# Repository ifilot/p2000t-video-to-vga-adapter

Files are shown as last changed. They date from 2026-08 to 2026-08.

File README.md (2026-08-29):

# P2000T video-to-VGA adapter

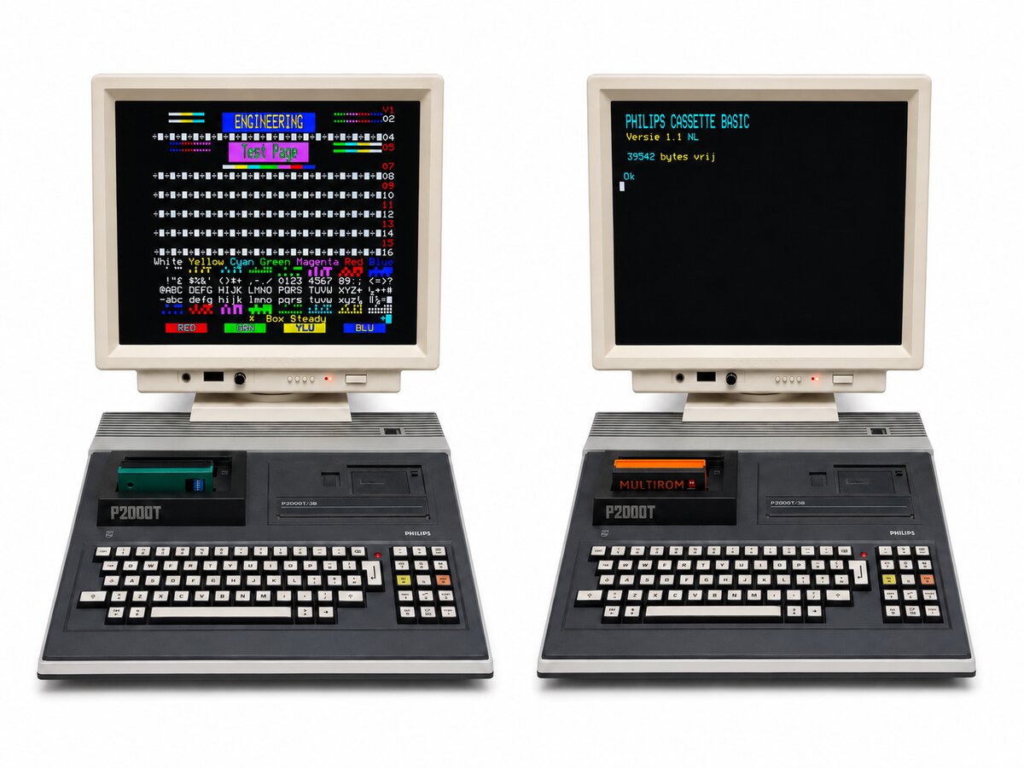
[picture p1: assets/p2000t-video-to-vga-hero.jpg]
Two Philips P2000T computers displaying the original RGBS output and converted VGA output






Hardware and firmware for converting the Philips P2000T RGBS output to
640×480 VGA using a Raspberry Pi Pico or Pico 2.

## Downloads

- [Latest Pico firmware](https://github.com/ifilot/p2000t-video-to-vga-adapter/releases/latest/download/p2000t-vid2vga-pico.uf2)
- [Latest Pico 2 firmware](https://github.com/ifilot/p2000t-video-to-vga-adapter/releases/latest/download/p2000t-vid2vga-pico2.uf2)
- [SAA5050 screen-test cartridge](https://github.com/ifilot/p2000t-video-to-vga-adapter/releases/latest/download/p2000t-screentest.bin)
- [Latest Windows capture viewer installer](https://github.com/ifilot/p2000t-video-to-vga-adapter/releases/latest/download/p2000t-vid2vga-capture-windows-setup.exe)
- [Latest portable Windows capture viewer](https://github.com/ifilot/p2000t-video-to-vga-adapter/releases/latest/download/p2000t-vid2vga-capture-windows.zip)

## Features

- 480×240 RGBs capture using PIO and DMA
- Triple-buffered, frame-boundary VGA updates
- Horizontally qualified CSYNC capture
- 640×480 at 60 Hz RGB444 VGA output
- Three selectable on-screen signal-loss designs
- On-board LED breathing while seeking and blinking during valid capture
- USB serial controls and capture statistics
- Pico 2 USB screen streaming at a target 25 FPS with a Qt 6 viewer
- Selectable raw, legacy guarded, sharp guarded, and Pico 2 three-sample
  126 MHz window reconstruction modes for studying transition instability
- CRC-protected persistence for every Pico 2 reconstruction mode

## Building

Install the Arm GNU toolchain, CMake, and Ninja. On Ubuntu or Debian, install
the required build packages with:

```sh
sudo apt update
sudo apt install cmake ninja-build gcc-arm-none-eabi \
  libnewlib-arm-none-eabi libstdc++-arm-none-eabi-newlib git python3
```

Configure and build the Pico firmware:

```sh
cmake -S . -B build -G Ninja -DCMAKE_BUILD_TYPE=Release -DPICO_BOARD=pico
cmake --build build --parallel
```

For Pico 2, use a separate build directory:

```sh
cmake -S . -B cmake-build-pico2 -G Ninja \
  -DCMAKE_BUILD_TYPE=Release -DPICO_BOARD=pico2
cmake --build cmake-build-pico2 --parallel
```

## USB controls

Connect to the Pico USB serial port and press `h` for help. Useful commands are
`s` for status, `[`/`]` for vertical position, `,`/`.` for sample phase, and
`;`/`'` for the odd-line phase correction. Use `{`/`}` to make the complete
captured line narrower or wider and `w` to reset that rate trim. `<`/`>` moves
the horizontal start, `d` toggles raw/guarded-second-tap reconstruction,
while `1`, `2`, or `3` selects the no-connection artwork.
Each phase tick is nominally 7.94 ns. Each rate step changes the PIO divider by
1/256 and moves the right edge by approximately 0.94 captured pixel while
leaving the sync-anchored left edge in place. Positive odd-line phase samples
odd physical source lines later; positive rate trim widens every line. Pico 2
v0.4.1 Pico 2 factory defaults use line-sliced `window-late` reconstruction
with phase `0`, odd-line correction `+1`, and rate trim `0`. The tuple was
validated against the complete animated teletext test page, including its
blue/white mosaic boundaries and both text polarities. The original Pico
retains raw reconstruction with phase-zero defaults.

Raw reconstruction exposes both 12 MHz samples in every nominal 6 MHz
SAA5050 source dot. Guarded-second-tap reconstruction uses the later sample
for both corresponding VGA pixels unless it matches neither the first tap nor
the following dot's first tap; that isolated intermediate color is replaced
by the current dot's first tap. Pico 2 window reconstruction captures a complete
high-resolution frame and decodes one source line per main-loop service slice;
this retained physical VGA output during live USB validation. It is enabled by
default on Pico 2 and can be omitted from a specialized build with
`-DP2000T_WINDOW_CAPTURE_ENABLED=OFF`. Existing explicitly saved settings remain
authoritative until the user invokes factory reset. Existing v0.3.x records are
migrated when next saved.

For a measured source period near 20092 us, start with rate trim `+2`. The
left-edge compensation allows the existing sample phase to remain unchanged;
compare both edges and also try `+1` because one divider step is necessarily
coarser than the calculated ideal correction.

On Pico 2, `c` starts the recommended continuous PackBits screen stream and
`r` starts an uncompressed stream. Press `q` or Escape to stop binary mode and
return to the console. The alignment and artwork commands remain available
silently while a binary stream is active, allowing the desktop viewer to
configure the adapter without interrupting capture. Stream protocol v4 adds a
64-bit Pico monotonic capture-completion timestamp to every record; the v0.4.1
viewer also accepts legacy v3 records. Factory reset restores and immediately
persists the known-good tuple, palette, and artwork in one USB operation.

> [!NOTE] 
> Screen streaming is intentionally excluded from the Pico/RP2040 build
> for now so its limited SRAM and established VGA timing remain unchanged.

## Pico 2 desktop capture viewer

The Windows viewer shows the P2000T screen live over USB and can save snapshots
as PNG files. It connects to the first detected Pico 2 automatically. When no
P2000T signal is present, it displays the same selected no-connection screen as
the VGA output.

Use **Adapter > Configure Pico 2** to adjust alignment, the independent
odd-line phase correction, and the horizontal sampling-rate trim; choose the
two-tap or 126 MHz window reconstruction; choose the no-connection artwork;
and tune all eight colors. Changes take effect
immediately, which makes calibration easy.
Settings can be restored, reset to their defaults, or saved to the Pico 2 for
the next power-on.

For capture-quality investigation, **Adapter > Record high-resolution
diagnostics** saves a full-frame 63 MHz CSYNC trace and repeated, sync-triggered
126 MHz raw RGBS bursts without reconstruction or palette conversion. See the
[diagnostic recording and analysis guide](docs/diagnostics.md).

For intermittent edge artifacts, **Adapter > Capture calibration sweep**
automatically tests an inclusive sample-phase x horizontal-rate range against
a static source screen. It waits a configurable number of frames after every
acknowledged change, saves multiple consecutive PNGs per setting, and records
the setting and source-frame sequence in a CSV manifest inside a timestamped
analysis directory. The odd-line correction remains fixed at its current
value, and the original live settings are restored after completion or
cancellation.

For unattended optimization, display the supplied SAA5050 screen-test
cartridge and choose **Adapter > Run engineering-screen autotune**. The viewer
forces sharp raw reconstruction, evaluates every phase/rate-trim pair, then
tunes the physical odd lines independently and validates the winner over a
longer run. It applies the result live without writing flash. Every retained
frame, modal candidate image, odd/even instability measurement, one-dot color
transient count, and selection decision is written to a timestamped analysis
directory. See the [engineering autotune guide](docs/engineering-autotune.md).

For AI-directed investigation, the invisible **Codex lab agent** owns the
Windows Pico connection without opening the viewer. Codex can query live state,
apply non-persistent sampling settings, explicitly persist a chosen tuple,
request settled multi-frame captures, receive modal/instability
metrics, inspect the PNGs, and adapt the next experiment without a person
operating a GUI. The Windows agent and WSL client exchange
atomic JSON files through `D:\tmp\p2000t-codex-lab`; see the
[Codex lab guide](docs/codex-lab.md).
The [windowed reconstruction design](docs/windowed-reconstruction.md) explains
the six-tap PIO path and its per-frame evidence counters.

Download either the installer or portable ZIP from [Downloads](#downloads).
The installer adds the viewer to the Start menu and includes an uninstaller.

## License

Firmware and viewer sources are
[GPL-3.0-or-later](LICENSES/GPL-3.0-or-later.txt). Hardware design files are
licensed under CERN-OHL-S-2.0; see [pcb/LICENSE.md](pcb/LICENSE.md).

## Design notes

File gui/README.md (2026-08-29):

# P2000T VID2VGA Capture

This deliberately small Qt 6 application discovers Raspberry Pi Pico USB CDC
ports, starts the Pico 2 binary RGB111 screen stream, verifies every frame with
CRC-32, and displays every 480×240 capture scanline twice as a square-pixel
480×480 image. It supports lossless PackBits or raw records and can save the
current frame as a PNG. When the P2000T signal is absent, the viewer reports
which of the three embedded no-connection screens the VGA output is showing
and reproduces that complete 640×480 screen from the same RGB444 artwork,
bitmap font, and overlay coordinates used by the firmware.

The application carries its retro-computing icon in the Qt resources and as a
multi-resolution Windows executable icon; no separate image files are needed
beside the packaged executable. Its menu actions use a matching late-1990s
Linux desktop-inspired icon set embedded in the same resource bundle.

When launched, the viewer attempts to connect to the first detected Pico USB
CDC port and start the selected stream encoding. Manual port refresh and
connect/disconnect controls remain available. Adapter > Configure Pico 2 opens
a modal with exact spin boxes for capture alignment, an artwork selector, an
independent odd-line sampling-phase correction, and a whole-line sampling-rate
trim, raw/guarded/sharp reconstruction and Pico 2 126 MHz window policies,
plus eight RGB444 color rows with channel spinners and color pickers.
Every edit is sent to the Pico
immediately for live debugging. Reload from Pico retrieves the saved flash
copy, Factory reset restores the known-good firmware defaults and immediately
persists them, and Save to Pico writes the current values as a CRC-protected
persistent copy. These controls require
firmware containing the matching structured control protocol. File > Exit and
Help > About provide the standard application menu entries.

**Adapter > Capture calibration sweep** automates repeatable alignment tests
against a static P2000T screen. Choose inclusive ranges for fine sample phase
and horizontal rate trim, the number of streamed frames to discard after each
change, and the number of consecutive PNGs to retain. The odd-line phase and
source-dot reconstruction mode stay at their current values. After choosing a
parent directory, the viewer creates a
timestamped `p2000t-analysis-*` directory containing lossless 480x480 PNGs,
`manifest.csv` with the requested settings, actual source-frame sequence, Pico
capture-completion timestamp, and host UTC receipt time, and `session.txt` with
the sweep and original settings. Progress can be
cancelled at any time; completed and cancelled sweeps restore the original
phase, odd-line phase, and rate trim. Partial images and the manifest are kept
when a sweep is cancelled or a write fails. The viewer remembers the last
selected parent directory. Setting acknowledgements are retried and time out
with the requested and last-reported values instead of leaving a sweep waiting
indefinitely.

**Adapter > Run engineering-screen autotune** is the unattended path for the
supplied SAA5050 test cartridge. It exhaustively scores all 357 phase/rate
combinations using unfiltered raw reconstruction, selects the base timing from
physical even lines, then tests all 21 odd-line corrections against physical
odd lines and validates the combined winner. The original live settings are
restored on cancellation or error. A successful winner remains active for
inspection but is deliberately not saved to flash. The output directory
contains every labeled retained frame, one modal PNG per candidate,
`frames.csv`, `candidates.csv`, `session.json`, and `result.json`. See
[the engineering autotune guide](../docs/engineering-autotune.md) for the
scoring definition and log schema.

The preferred AI workflow uses the separate, invisible
`p2000t-vid2vga-lab-agent.exe`; the viewer is not required. The agent and viewer
both support the same shared-directory **Codex lab bridge**. On a Windows
development machine its default root is
`D:\tmp\p2000t-codex-lab`. The repository client
`tools/p2000t_lab.py` can query status, shut down the agent, or submit one
acknowledged experiment at
a time, including optional phase, rate, odd-line phase, reconstruction,
reference-modal, settling-frame, and capture-frame controls. Successful
experiments leave their live setting active so Codex can adapt from it;
cancellation and errors restore
the pre-experiment timing. Only the separate, explicit `save` command writes
the current live tuple to Pico flash and waits for a matching stored-state
acknowledgement. Each run saves the request, exact frames and sequences, modal
image, spatial/temporal metrics, firmware correction counters, and result JSON. See
[the Codex lab guide](../docs/codex-lab.md).

USB stream protocol v4 carries a 64-bit Pico monotonic capture-completion
timestamp. The viewer accepts both v4/72-byte and legacy v3/64-byte headers and
shows the current device timestamp in its status bar.

The firmware command `c` starts the recommended PackBits stream, `r` starts a
raw stream, and `q` returns it to the normal USB console. Streaming is currently
compiled into the Pico 2 firmware only.

## High-resolution diagnostics

**Adapter > Record high-resolution diagnostics** records a lossless CSYNC
timing trace followed by repeated 252 MHz raw RGBS bursts covering up to sixteen
contiguous physical source lines. The viewer validates each CRC-protected record
before appending it to `capture.p2td` and writes a CSV byte index alongside it.
See [the diagnostic format and analysis guide](../docs/diagnostics.md).

## Windows build with MSYS2

Open an **MSYS2 UCRT64** shell and install the compiler, CMake, Ninja, and Qt 6:

```sh
pacman -S --needed mingw-w64-ucrt-x86_64-toolchain \
  mingw-w64-ucrt-x86_64-cmake mingw-w64-ucrt-x86_64-ninja \
  mingw-w64-ucrt-x86_64-qt6-base
```

Configure and compile from the repository root:

```sh
cmake -S gui -B build-gui -G Ninja -DCMAKE_BUILD_TYPE=Release
cmake --build build-gui --parallel
```

The executable is `build-gui/p2000t-vid2vga-capture.exe`. To prepare a
self-contained development directory with the required Qt DLLs:

```sh
mkdir -p build-gui/package
cp build-gui/p2000t-vid2vga-capture.exe \
  build-gui/p2000t-vid2vga-lab-agent.exe build-gui/package/
windeployqt6 --release --no-translations \
  --exclude-plugins qpdf,qsvg,qsvgicon \
  build-gui/package/p2000t-vid2vga-capture.exe
```

MSYS2 runtime DLLs reported by `ldd` may also need to be copied into the
package when it will run outside an MSYS2 UCRT64 environment. Redistributed Qt
DLLs must be accompanied by their corresponding terms from
`/ucrt64/share/licenses/qt6-base`. The SVG and PDF plugins are excluded because
the viewer does not use them. GitHub Actions performs both steps for the
release ZIP.

## Windows graphical installer

The preferred package is an NSIS 3 offline installer inspired by the P2000M
viewer. It installs the complete deployed application under Program Files,
creates desktop and Start-menu shortcuts, upgrades an existing installation
in place, and registers a conventional Windows uninstaller. Install NSIS 3
and make `makensis.exe` available on `PATH`, then run from PowerShell after
preparing a self-contained deployment directory:

```powershell
gui/packaging/create_windows_installer.ps1 `
  -Stage dist/viewer -Version 0.4.1 `
  -Output dist/p2000t-vid2vga-capture-windows-setup.exe `
  -WorkDirectory installer-work
```

The stage must contain `p2000t-vid2vga-capture.exe`, all runtime DLLs, and
`licenses/GPL-3.0-or-later.txt`. GitHub Actions constructs that tree, compiles
both the installer and portable ZIP on every push and pull request, checks the
installer archive with 7-Zip, and performs fresh-install, in-place-upgrade,
and uninstall smoke tests. Tagged releases publish only after this job passes.

The installer is currently unsigned because no Authenticode certificate is
configured. Windows SmartScreen may therefore request confirmation on first
launch.

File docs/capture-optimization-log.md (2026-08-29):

# Capture optimization progress log

This log records measured checkpoints and single-variable experiments made
during the withdrawn confidence-guard candidate validation. Candidate firmware
is kept only when it improves temporal stability without modal-image damage,
capture deadline failures, or host-test regressions.

## 2026-08-29 — v0.4.1 whole-screen default

A second animated teletext page exposed severe blue-on-white text instability:
the raw phase -1 tuple changed an average 148.3 pixels per captured frame in
that panel, with 280 pixels in the worst frame. Optimizing only that panel led
to `window-early`, phase -2, which made the panel perfectly stable but increased
white-caption instability from 7.3 to 41.4 pixels per frame and visibly damaged
other blue/white transitions. It was rejected as an overfit.

The complete screen was then divided into title, mosaic, blue-on-white text,
white-on-blue text, animated prompt, and footer bands. Intentional prompt
animation was tracked separately. The balanced `window-late`, phase 0, physical
odd correction +1, rate trim 0 candidate produced the following 100-frame
result:

| Region | Raw changes/frame | v0.4.1 changes/frame |
|---|---:|---:|
| Title | 16.2 | 9.1 |
| Mosaic | 50.3 | 32.7 |
| Blue-on-white text | 148.3 | 22.8 |
| White-on-blue text | 7.3 | 5.1 |
| Footer | 6.4 | 2.8 |

Run `experiment-20260829-071058-e1868a06` completed 100 frames with zero
deadline misses and 70 modal mismatches across 115,200 pixels. The physical VGA
screen retained sync and the user accepted the complete screen, including both
text polarities and the mosaic boundary. This tuple replaces the v0.4.0 raw
fallback as the Pico 2 v0.4.1 factory default; Pico 1 remains unchanged.

## 2026-08-29 — line-sliced reconstruction and live VGA recovery

The complete-frame capture was retained, but its monolithic 240-line decode
was replaced with one source line per core-0 service slice. This bounds each
reconstruction burst to 720 source bytes, 240 destination bytes, and lookup
traffic before returning control. The physical engineering image remained
visible throughout both validation runs; unlike the prior batch, VGA did not
lose signal. The slower decoder deliberately misses source-frame boundaries,
so window timing accepts periods up to 85 ms while raw timing remains limited
to 19–21.2 ms.

| Run | Tuple | Frames | Robust ppm | Reference mismatch | Decision |
|---|---|---:|---:|---:|---|
| `experiment-20260829-064815-9533c047` | confidence, phase 0, odd +1 | 20 | 128.35 | 28 pixels | VGA checkpoint passed |
| `experiment-20260829-064935-043262fb` | confidence, phase 0, odd +1 | 100 | 149.19 | 26 pixels | Keep experimental |
| `experiment-20260829-064957-4a03cece` | raw, phase -1, odd +1 | 100 | 142.67 | exact reference | Retain factory tuple |

All three runs reported zero deadline misses. The short window run looked
promising, but the matched 100-frame comparison favored raw by 6.52 ppm. The
line-sliced engine therefore solves the VGA/SRAM failure without yet providing
a universal image-quality gain.

## 2026-08-29 — v0.4.1 frame-batched reconstruction

The former line-rate six-tap engine was replaced with complete-frame DMA into
the logic analyzer's shared scratch SRAM followed by one batched decode. This
removes reconstruction from the 64 us source-line deadline. The USB stream
remained valid, reported no deadline misses, and protocol-v4 manifests carried
nonzero Pico capture timestamps throughout the trials.

| Run | Tuple | Robust ppm | Reference mismatch | Decision |
|---|---|---:|---:|---|
| `experiment-20260829-060858-fc4c7788` | raw, phase -1, odd +1 | 141.98 | reference | Retain factory tuple |
| `experiment-20260829-061500-6bdb5bf9` | confidence, phase 0, odd +1 | 158.22 | 2 recolored pixels vs yesterday | Exact geometry; no temporal win |
| `experiment-20260829-061558-eb1baade` | confidence, phase -1, odd +1 | 282.87 | 186 pixels | Reject |
| `experiment-20260829-061611-56253322` | confidence, phase +1, odd +1 | 202.65 | 46 pixels | Reject |
| `experiment-20260829-061624-d8eaee63` | confidence, phase 0, odd 0 | 190.70 | 35 pixels | Reject |

The batched confidence result reproduces the withdrawn candidate's sharp modal
geometry to within two source pixels, but it misses the immediately following
vertical acquisition opportunity and therefore captures at approximately 25
source frames per second. The viewer receives every second capture at roughly
80.37 ms intervals. Because it did not beat the stable raw tuple's temporal
score on the current engineering page, it remains selectable engineering code
rather than the v0.4.1 factory setting.

The USB factory-reset path was tested after applying a deliberately non-default
live tuple. One command restored raw reconstruction, phase -1, physical odd
phase +1, and rate trim 0, persisted them, and returned a configuration state
with both `stored_available` and `matches_stored` set.

Final live VGA checkpoint `experiment-20260829-062421-33b6b09d` overruled the
otherwise healthy USB evidence: while frame-batched `window-confidence` was
active, the physical VGA monitor lost signal. USB continued receiving valid
frames. Issuing `factory-reset` restored raw/two-tap capture, valid signal, and
the saved known-good tuple. All window modes are consequently gated off in the
v0.4.1 release candidate.

## 2026-08-29 — stable v0.4.0 recovery

Live hardware testing separated two independent symptoms. The six-tap window
engine could retain a correct, locked USB framebuffer while the VGA source
image was completely black. Switching only reconstruction to raw immediately
restored the monitor. Removing its 64 KiB lookup tables and calculating the
same result directly still overloaded the line-rate IRQ severely enough to
stop USB service. Continuous window reconstruction is therefore unavailable
in stable v0.4.0 pending a frame-batched or otherwise contention-free design.

The current static screen was then optimized only across settings which retain
the proven two-tap capture engine. Rate trim remained zero because adjacent
steps had already shown severe horizontal drift.

| Run | Tuple | Robust ppm | Coherent outliers | Modal mismatch | Decision |
|---|---|---:|---:|---:|---|
| `experiment-20260829-053012-63116af9` | raw, phase 0, odd +1 | 707.47 | 0/30 | reference | Baseline |
| `experiment-20260829-053025-28f511d5` | raw, phase -1, odd +1 | 137.15 | 10/30 | 79 | Best raw timing |
| `experiment-20260829-053109-bec08b96` | raw, phase -2, odd +1 | 325.33 | 7/30 | 128 | Reject |
| `experiment-20260829-053118-b5e45f42` | raw, phase -1, odd 0 | 184.10 | 6/30 | 90 | Reject |
| `experiment-20260829-053131-5a84b7f4` | raw, phase -1, odd +2 | 771.12 | 0/30 | 78 | Reject |
| `experiment-20260829-053043-c415dcb3` | sharp, phase 0, odd +1 | 572.62 | 1/30 | 214 | Reject: spatial changes |
| `experiment-20260829-053056-f09a0a8a` | sharp, phase -1, odd +1 | 141.32 | 5/30 | 284 | Reject: spatial changes |
| `experiment-20260829-053140-4b289fb6` | guarded duplicate, phase -1, odd +1 | 20.98 | 6/30 | 1,035 | Reject: blurred geometry |
| `experiment-20260829-053156-8ff7d195` | raw, phase -1, odd +1 | 143.66 | 20/100 | 81 | Keep and persist |

The stable v0.4.0 Pico 2 factory tuple is consequently raw/two-tap, phase -1,
physical odd-line phase +1, and rate trim 0. The long validation retained
8,013 horizontal transitions and had no capture deadline failures.

## 2026-08-28

### Checkpoint C0 — withdrawn confidence-candidate tuple

- Run: `experiment-20260828-210630-9db12c91`
- Settings: `window-confidence`, phase 0, odd-line phase +1, rate trim 0.
- Reference fidelity: exact; 0 erased, 0 filled, 0 recolored pixels.
- Robust temporal instability: 50.0878 ppm over 87/120 frames; median 7
  changed source pixels; 502 robust changed-pixel observations.
- Capture safety: 0 deadline-miss frames.
- Spatial audit: every frame is best aligned at horizontal shift 0. Remaining
  ordinary changes occupy 67 fixed edge sites and toggle only between adjacent
  colors. The 33 coherent outliers are a periodic 133–143-pixel source change
  concentrated in seven bottom rows and are treated as source animation, not
  lateral capture jitter.

### Experiments

| ID | Single change | Robust ppm | Modal mismatch | Deadline frames | Decision |
|---|---|---:|---:|---:|---|
| C1 `experiment-20260828-211036-58e97823` | phase -1 | 701.2442 | 116 | 0 | Reject: 14.0× more jitter and 102 erased pixels |
| C2 `experiment-20260828-211057-a9da6fc7` | phase +1 | 503.4722 | 66 | 0 | Reject: 10.1× more jitter and 62 filled pixels |
| C3 `experiment-20260828-211117-3b75ef3c` | odd phase 0 | 107.8318 | 19 | 0 | Reject: 2.2× more jitter and 19 erased pixels |
| C4 `experiment-20260828-211137-d3f28b0f` | odd phase +2 | 216.0704 | 33 | 0 | Reject: 4.3× more jitter and 33 filled pixels |
| C5 `experiment-20260828-211157-6595f22b` | rate trim -1 | 2691.3339 | 4558 | 0 | Reject: severe horizontal drift and modal damage |
| C6 `experiment-20260828-211217-b946bc51` | rate trim +1 | 2397.4971 | 3207 | 0 | Reject: severe horizontal drift and modal damage |
| C7 `experiment-20260828-211238-f63362ff` | baseline repeat | 50.0801 | 1 | 0 | Keep C0: confirms approximately 0.01 ppm run-to-run variance |
| C8 `experiment-20260828-212231-4bf062e0` | physical-even fixed late endpoint | 36.7757 | 4 | 0 | Reject: 26.6% less jitter, but four repeatable boundary recolors |
| C9 `experiment-20260828-213327-e98ae5db`, `experiment-20260828-213357-809da1bb` | two-frame confirmation on guarded parity | 32.31–34.43 | 1–2 | 0 | Reject: repeatable boundary recolor; priority 0x80 variants also stalled |
| C9b `experiment-20260828-213623-15b305d1` | confirm only unresolved pairs | 48.5364 | 0 | 0 | Reject: only 3% gain for 14.4 KiB SRAM and ambiguous-edge latency |
| C10 `experiment-20260828-214354-bcb385d1` | capture DMA IRQ priority 0x40 only | 50.9259 | 0 | 0 | Keep: exact image fidelity and prevents reproducible startup scanline stalls; later 0x80 diagnostics failed CRC too, so CRC was not caused by priority |

### Raw checkpoint R0 — dominant bottom edges

- Diagnostic: `diagnostic-20260828-211726-13e2ee1b`, physical lines 280–295.
- 56 CRC-valid bursts were preserved; record 59 failed transport CRC and the
  remaining requested bursts were intentionally rejected.
- No capture overruns or PIO RX stalls occurred.
- Aligning every line independently to its measured CSYNC edge located the
  exact window start at raw tick 2153. Replaying the production confidence
  policy over physical lines 287–293 produced 198 temporal disagreements and
  three modal mismatches. Replacing only the physical-even confidence guard
  with a fixed late-window endpoint predicted 106 disagreements and four modal
  mismatches. Live C8 confirmed lower jitter but also confirmed the damage.

An exhaustive replay of every three-position aperture within ±3 raw ticks
found the production `[-1, 0, +1]` aperture to be the only candidate with zero
modal changes. The nearest lower-jitter aperture, `[-2, 0, +1]`, reduced the
subset to 106 disagreements but changed two modal pixels. A symmetric
`[-2, 0, +2]` aperture increased the subset to 414 disagreements and changed
14 modal pixels, so wider 126 MHz sampling was rejected without a live flash.

### Raw checkpoint R1 — full-clock diagnostics

- Diagnostic: `diagnostic-20260828-215147-4bebab42`, physical lines 287–293.
- The raw diagnostic sampler ran at 252 MHz while production capture remained
  at 126 MHz. Twenty-four CRC-valid bursts were analyzed.
- Production sampling aligns at diagnostic tick 4307 with the equivalent
  `[-2, 0, +2]` half-tick aperture. It produced 28 temporal disagreements and
  one mismatch against the reference subset.
- A three-adjacent-sample 252 MHz aperture produced 74 disagreements and two
  reference mismatches. Exhaustive half-tick replay found no wider or denser
  aperture with better fidelity, so changing the production sampler to
  adjacent 252 MHz samples was rejected.

### Diagnostic transport checkpoint

- Stress run: `diagnostic-20260828-222207-81c9ed91`, physical lines 121–136.
- All 23 records, including twenty maximum-size raw bursts, reached the
  analyzer with valid CRCs and no capture overrun or PIO RX stall.
- A deliberately observed rejected attempt was preserved and retransmitted by
  the guarded ACK/retry protocol, confirming recovery rather than silent loss.

## 2026-08-29

### Raw checkpoint R2 — full-screen transition map

- Fifteen validated 252 MHz blocks cover physical lines 57–296 with 132 raw
  bursts and 1,013,760 reconstructed pixel observations.
- Replaying the confidence candidate produced 2,609 temporal disagreements and one modal-reference
  mismatch. Most disagreements were confined to the animated top block.
- Applying the late-confidence rule globally reduced only fourteen
  disagreements and introduced three new modal errors, confirming that the
  previous fixed-late experiment is not a safe general solution.
- A raw `c->1` pair with an early outlier and two equal late samples was the
  only repeated transition-specific exception: eight events at three sites,
  all matching the late output. The other apparently safe keys had at most
  seven observations and were not promoted to live tests.

### Experiments C11–C12 — targeted `c->1` exception

| ID | Change | Robust ppm | Modal mismatch | Decision |
|---|---|---:|---:|---|
| C11 `experiment-20260828-223932-1a66cb8b` | accept settled-late `c->1` | 49.3580 | 0 | Repeat required |
| C11r `experiment-20260828-223949-da3a14ea` | same, repeat | 48.2148 | 0 | Repeat looked better than the old 50.08 ppm checkpoint |
| C11l `experiment-20260828-225417-ceed4697` | same, 300 frames | 46.7355 | 0 | Reject: disputed pixel changed in 213/299 frame transitions |
| control `experiment-20260828-224307-b6d1f6d6` | contemporaneous confidence guard | 39.8915 | 1 filled | Reject as control: low score came from freezing the disputed pixel to the wrong modal color |
| C12 `experiment-20260828-224825-959f30b9` | require same accepted pair in prior frame | 44.9633 | 0 | Reject: disputed pixel still changed in 64/119 transitions and requires frame history |

The single disputed source pixel was viewer coordinate `(321, 472)`. C11
showed its reference color in 74/120 frames and C12 in 70/120, while the first
control showed it in only 30/120 and therefore appeared steadier by freezing
to the wrong color. A later exact confidence-candidate control showed 71/49 observations and
68 changes over 119 transitions. The 300-frame C11 run showed 187/113
observations but 213 changes over 299 transitions (71.2%). This proves a
threshold tradeoff rather than a universally correct endpoint: accepting the
late half-dot repairs modal geometry but exposes the unstable analog boundary.
Both firmware candidates were removed.

### Raw checkpoint R3 — measured source line rate

- Nineteen valid 252 MHz diagnostic sessions supplied 2,214 complete line
  periods. The combined mean was about 16,125.175 diagnostic ticks versus the
  nominal 16,128 ticks, so this P2000T source is approximately 175.19 ppm
  faster than nominal.
- Physical-even lines averaged 16,125.1105 ticks and physical-odd lines
  16,125.2399 ticks. The 0.1293-tick difference is about 0.5 ns and rules out
  materially different odd/even line lengths.
- The ordinary PIO rate-trim step is 1/256 of divider 2, approximately 1,953
  ppm. It is therefore roughly eleven times too coarse to track this measured
  source-rate error.

### Experiment C13 — fine system-clock rate lock

RP2350 can express a much finer rate correction in its fractional system-clock
divider. Offline replay modeled +169 ppm and phase +1. Preserving only the
repeated settled `d->c` and `d->9` transitions removed all modal-reference
errors across the 1,013,760-observation corpus. This justified a live trial,
but did not justify retaining it without live confirmation.

An initial PLL trial was deliberately discarded after a raw clock check found
16,064.7 samples per line. The requested 1,530 MHz VCO was not an integer
multiple of the 12 MHz crystal and had been realized as 1,524 MHz. The corrected
build used an exact 1,536 MHz VCO and measured 16,127.92 samples per line
(median 16,128), confirming that the intended rate lock was physically present.

| Run | Live tuple | Robust ppm | Modal mismatch | Decision |
|---|---|---:|---:|---|
| `experiment-20260828-231239-0472237f` | phase 0, odd +1 | 762.2975 | 69 | Reject |
| `experiment-20260828-231255-3e5cc6d3` | phase +1, odd +1 | 84.2821 | 2 | Best rate-locked tuple, still worse than the confidence candidate |
| `experiment-20260828-231316-fefbe374` | phase +1, odd 0 | 130.6801 | 18 | Reject |
| `experiment-20260828-231324-fa6375df` | phase +1, odd +2 | 479.9934 | 56 | Reject |
| `experiment-20260828-231545-dbef6eed` | restored confidence candidate | 49.8400 | 0 | Keep |

All C13 runs had zero deadline-miss frames. The experiment shows that matching
the average source line rate does not improve this capture: it shifts which
analog boundaries enter the three-sample aperture and creates more unstable or
incorrect decisions. The Pico and firmware source were restored to exact
the withdrawn confidence-candidate behavior. Further temporal filtering would suppress visible glitter
only by adding stale pixels or motion blur, failure modes already demonstrated
by C9/C12, so no narrower firmware correction was retained.

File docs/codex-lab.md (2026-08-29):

# Codex lab bridge

The Codex lab bridge uses the invisible `p2000t-vid2vga-lab-agent.exe` as a
local laboratory instrument. The agent retains ownership of the Windows Pico
serial port while Codex in WSL controls experiments through atomic files in a
shared directory. The graphical viewer is not required.
This is more reliable than attempting to open a Windows COM device from WSL
and prevents two processes from competing for the Pico.

The bridge starts automatically with the lab agent (and is also available when
a human deliberately runs the viewer). Its Windows default is:

```text
D:\tmp\p2000t-codex-lab
```

The same directory is `/mnt/d/tmp/p2000t-codex-lab` in WSL. Set
`P2000T_LAB_ROOT` before launching either component to override it.

## Codex-facing client

From the repository root:

```sh
python3 tools/p2000t_lab.py status
python3 tools/p2000t_lab.py save
python3 tools/p2000t_lab.py factory-reset
python3 tools/p2000t_lab.py experiment \
  --phase -2 --odd-phase 1 --rate-trim 2 \
  --reconstruction window-early --settle 3 --frames 40 \
  --tag "engineering screen, left-edge hypothesis"
python3 tools/p2000t_lab.py cancel
python3 tools/p2000t_lab.py shutdown
```

The client prints the structured response and returns nonzero when a request is
rejected or an experiment fails. Codex can then open the returned PNG paths,
compare metrics, and issue the next experiment. Settings omitted from an
experiment inherit their current live values. A zero-frame experiment applies
and acknowledges settings without saving images.

Experiments operate only on live phase, physical odd-line phase, line-rate
trim, and reconstruction. Available reconstruction names are `raw`, `guarded`,
`sharp`, `window-center`, `window-channel`, `window-early`, `window-late`, and
`window-confidence`. The latter adds the parity-aware unanimous-evidence
guard. Window modes require Pico 2 and acquire three
consecutive 126 MHz samples around every retained output sample. Experiments
never write flash.
Successful settings remain active for the next adaptive step; an error,
cancellation, signal loss, or disconnection restores the settings which were
active before that experiment. The separate, explicit `save` command persists
the current live tuple and succeeds only after the Pico reports that it matches
the stored tuple. `factory-reset` restores the firmware's known-good tuple,
palette, and artwork, persists them immediately, and likewise waits for a
matching saved-state acknowledgement.

## Directory protocol

The client atomically renames complete JSON files into `requests/`. The viewer
archives accepted input under `archive/` before execution and atomically writes
the corresponding `responses/<id>.json`. `bridge-status.json` is a once-per-
second heartbeat containing connection, signal, busy, and complete live-setting
state.

An experiment request has protocol version 1:

```json
{
  "protocol": 1,
  "id": "edge-study-001",
  "command": "experiment",
  "tag": "white-to-blue transition",
  "reference_run": "edge-study-baseline",
  "settings": {
    "phase": -2,
    "odd_line_phase": 1,
    "rate_trim": 2,
    "reconstruction": "raw"
  },
  "settle_frames": 3,
  "capture_frames": 40
}
```

Valid commands are `status`, `experiment`, `diagnostic`, `save`,
`factory-reset`, `cancel`, and `shutdown`.
Ranges are validated before any firmware command is sent. Every setting tuple
is followed by an explicit firmware state request; capture starts only after
the Pico reports the complete requested tuple. Missing acknowledgements are
retried and bounded by a timeout.

Each experiment creates `runs/<id>/` containing:

- `request.json` with target and original live settings;
- `frames.csv` and lossless, sequence-labeled PNGs;
- `modal.png` for a capture with at least one frame;
- `result.json` with temporal instability, physical row-parity diagnostics,
  robust low-change-frame metrics, coherent high-change-frame counts,
  one-pixel island/third-color counts, horizontal transitions, score, exact
  firmware reconstruction telemetry, and optional reference-modal fidelity.

Passing `--reference-run <id>` compares the new modal with
`runs/<id>/modal.png`. The result classifies every mismatch as an erased,
filled, or recolored pixel. Robust temporal fields use frames at or below the
larger of 32 changed pixels and four times the median frame mismatch count.
Frames above that threshold remain logged as `coherent_outlier_frames` rather
than silently disappearing from the ordinary instability total.

Every `frames.csv` row records the Pico capture-completion timestamp and host
UTC receipt time, active engine, samples per output pixel, corrected and
ambiguous sample counts, corrections per RGB channel, and whether a capture
deadline was missed. `result.json` also aggregates those values.

Bridge experiments remain non-persistent. Flash is changed only by an explicit
`save` or `factory-reset` command or the ordinary configuration UI. Pico 2
v0.4.1 uses line-sliced `window-late`, phase 0, odd-line +1, and rate trim 0 as
its power-on and factory default when no valid saved record is present. The
engine is available in ordinary Pico 2 release builds after whole-screen and
physical VGA validation. Existing saved settings remain authoritative until an
explicit `factory-reset`; the original Pico retains raw phase-zero defaults.

The transport test can run without hardware: a `status` request still returns
viewer state, while an experiment is explicitly rejected as unavailable when
the Pico or P2000T signal is absent.

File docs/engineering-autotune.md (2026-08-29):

# Engineering-screen autotune

The viewer can run a complete sampling experiment without manual setting
changes. Load `screentest/screentest.bin` on the P2000T, leave that static page
visible, connect the viewer, and choose **Adapter > Run engineering-screen
autotune**.

## What the run changes

The experiment is deliberately staged instead of taking a Cartesian product
of every control:

1. It forces raw reconstruction and tests all 21 sample phases against all 17
   horizontal rate trims. Physical even source lines select the shared base
   phase and rate.
2. It holds that winner fixed and tests all 21 odd-line phase corrections.
   Only the physical odd-line score selects this correction. The viewer maps
   physical parity through the configured first visible source line, so an odd
   starting line does not accidentally reverse the comparison.
3. It captures a longer validation run using the combined winner.

Raw reconstruction is mandatory during this experiment. A reconstruction mode
which duplicates samples can reduce temporal differences simply by discarding
horizontal information; such a blurred image must not win a sampling test.

The successful settings remain active but are not saved to flash. Canceling,
disconnecting, or encountering an error restores phase, rate trim, odd-line
phase, and reconstruction mode to their original live values.

## Score

For each setting, the viewer builds a per-pixel modal image from the retained
frames. It evaluates one scanline from each vertically duplicated viewer pair
and records:

- samples that differ from the per-pixel temporal mode, split by logical
  odd/even row;
- the median per-frame mismatch count and a separate robust instability value
  which excludes coherent high-change frames while retaining their count;
- one-pixel islands whose two horizontal neighbors agree;
- one-pixel third colors which match neither side of a color transition;
- the modal image's horizontal transition count as a sharpness diagnostic.

The primary score is:

```text
instability_ppm + 4 * one_dot_artifact_ppm
```

All raw measurements and the weighting are logged. The algorithm selects the
lowest physical-even score for base phase/rate and the lowest physical-odd
score for odd-line phase. An exact tie prefers the smallest total absolute
correction. The longer validation score is reported rather than used to search
again.

This is an objective engineering heuristic, not a claim that every visible
defect has one cause. The preserved captures and modal images allow the score
and winner to be challenged or reanalyzed later.

The ordinary instability total remains authoritative for the autotune score.
The robust fields are additional diagnostics: they prevent a periodic source
animation, such as a flashing SAA5050 test region, from being mistaken for a
sampling regression while ensuring those frames remain visible in the log.

## Output directory

Each run creates `p2000t-autotune-YYYYMMDD-HHMMSS` beneath the selected parent:

- `session.json`: viewer version, run parameters, original settings, source
  line parity mapping, reconstruction constraint, and score formula;
- `frames.csv`: exact setting, stage, source-frame sequence, Pico capture
  timestamp, host UTC receipt time, and filename for every retained PNG;
- `candidates.csv`: raw and normalized temporal/spatial metrics for every
  candidate plus its modal PNG filename;
- `modal_*.png`: temporal modal image for every candidate;
- `result.json`: phase/rate winner, final recommended settings, validation
  metrics, selection rule, and explicit `written_to_flash: false` state;
- labeled `*.png` files: all retained source frames, including validation.

The default run evaluates 378 search candidates with eight retained frames
each, followed by 100 validation frames. At a 25 FPS viewer stream it takes a
little over two minutes plus PNG and USB overhead and writes 3,124 retained
frames. Increasing frames per candidate improves sensitivity to rare glitches
at the cost of a proportionally longer run.

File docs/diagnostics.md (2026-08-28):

# High-resolution diagnostic captures

The Pico 2 diagnostic recorder is a lossless logic-analyzer path intended for
studying horizontal timing, odd/even-line displacement, and unstable RGB
transitions. It runs alongside the normal capture engine on the RP2350's PIO2.

Use **Adapter > Record high-resolution diagnostics** in the viewer. Select a
physical source line, one to sixteen contiguous lines, and the number of
repeated bursts. Keep the P2000T image unchanged until recording completes.

Each session contains:

- `session.json`: requested acquisition and active alignment settings;
- `capture.p2td`: authoritative, append-only binary records;
- `manifest.csv`: byte offsets and metadata for every validated record.

The first payload is a roughly 22 ms, 63 MHz one-bit CSYNC trace. It is followed
by repeated RGBS bursts sampled at the full 252 MHz system clock. Each nominal
scanline contributes 16128 four-bit observations, so a sixteen-line burst
contains 258048 samples and 129024 payload bytes. RGB and CSYNC are conditioned,
active-low/active-high input values exactly as seen at the GPIO pins; no
reconstruction or palette mapping is applied.

The firmware timestamps the sampler trigger and DMA completion independently.
Both measured and expected capture durations are stored in every data header;
an overrun flag is set when the measured interval exceeds the expected interval
by more than 50 microseconds. This makes memory-bus stalls visible in the saved
evidence rather than silently accepting a distorted time axis.

A second DMA channel is chained to each acquisition and disables both PIO2
state machines at the exact requested word count. Because the sampler cannot
then stall merely from continuing past the end of its buffer, the PIO RX-stall
flag in a data record identifies a genuine acquisition-time FIFO stall. Treat
any record carrying either timing-integrity flag as suspect during analysis.

## Binary format

Every record starts with a 72-byte little-endian header and the magic `P2DG`.
The wire stream follows each record with a duplicate of its final 64 payload
bytes and an eight-byte guard marker. The viewer validates the complete record
through this marker, acknowledges valid data, and requests retransmission after
a CRC failure. It discards the duplicate and marker, so guards are never stored
in `capture.p2td`; a rejected attempt is retained separately for investigation.
Payload words are
little-endian `uint32_t` values. Samples within each word are
chronological from its most significant bits: 32 one-bit CSYNC observations or
eight four-bit RGBS nibbles. The payload has a standard reflected CRC-32.
Header offsets and record identifiers are defined in
`src/p2000t_diagnostic_protocol.h`.

The stream contains, in order, a session record, one timing record, one raw
record per requested repetition, and a complete record. A cancelled session
still ends with a CRC-protected complete record carrying the cancelled flag;
already written data remains valid.

## Initial analysis

Run:

```sh
python3 tools/analyze_diagnostics.py path/to/p2000t-diagnostics-*/
```

The script validates every header, sequence number, session identifier, payload
length, and CRC before producing `analysis/timing-edges.csv`,
`analysis/raw-sync-edges.csv`, `analysis/unstable-samples.csv`, and
`analysis/summary.json`. Preserve `capture.p2td`; derived CSV files can always
be regenerated.

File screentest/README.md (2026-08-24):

# SAA5050 screen-test cartridge

This directory builds a signed 16 KiB SLOT1 cartridge image for the P2000T.
It renders the static 24-by-40 SAA5050 test page recovered from the `DATA`
statements in the tokenized BASIC cassette
[`SAA5050 Test Page.cas`](https://github.com/p2000t/software/blob/main/cassettes/Grafische%20demo%27s/SAA5050%20Test%20Page.cas).
The control bytes are described in the
[P2000T SAA5050 overview](https://www.retrospace.nl/Philips_P2000T_homecomputer.html).

Build and validate it with:

```sh
make
make verify
```

The final flashable image is `screentest.bin`. The build requires `z80asm`
and Python 3. The signer covers the first 8 KiB bank using the count and
16-bit checksum fields in the P2000 cartridge header.

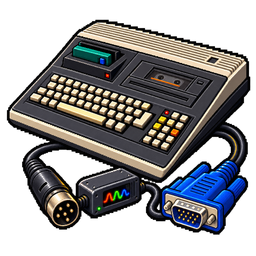
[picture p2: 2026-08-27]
gui/assets/p2000t-capture-v2.png

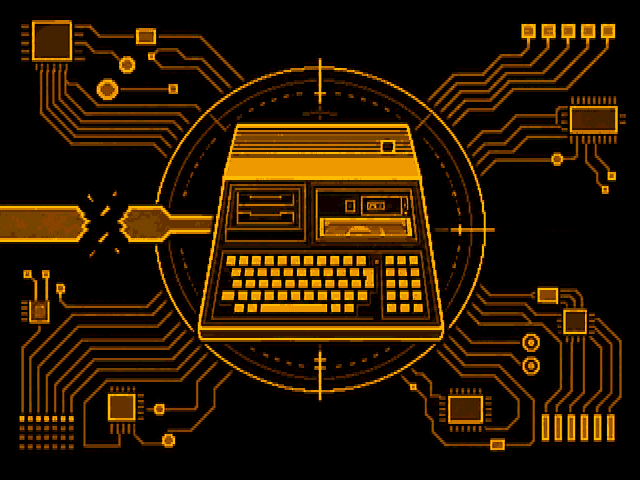
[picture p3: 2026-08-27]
assets/no_connection/amber_circuit.png

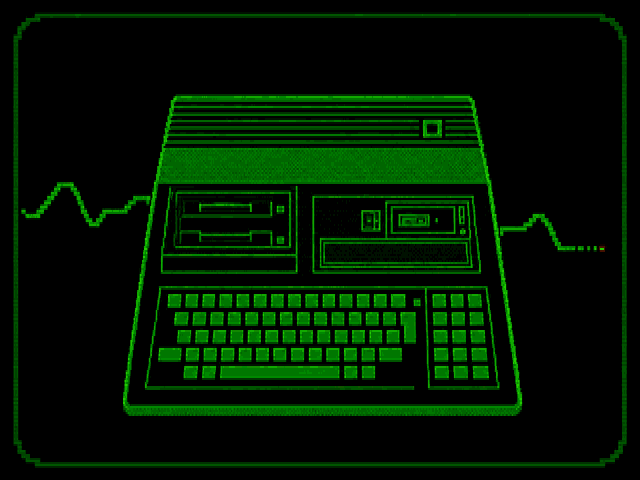
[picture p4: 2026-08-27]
assets/no_connection/green_phosphor.png

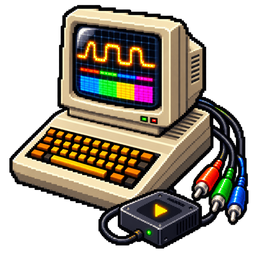
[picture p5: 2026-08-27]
gui/assets/p2000t-capture.png

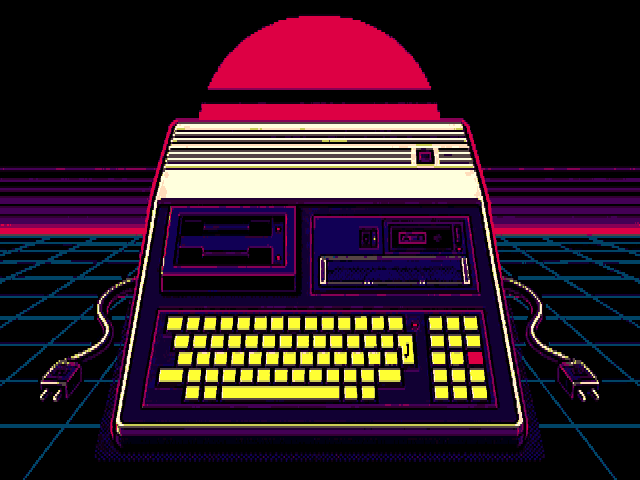
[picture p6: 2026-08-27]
assets/no_connection/synthwave.png

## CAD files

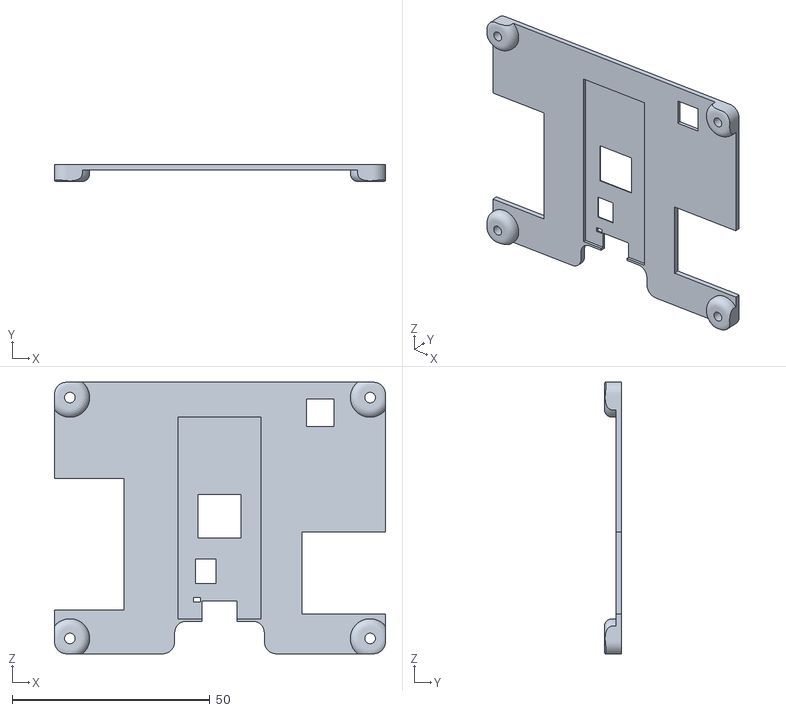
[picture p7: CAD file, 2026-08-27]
enclosure/top.stl
83.7 x 4.40 x 68.8

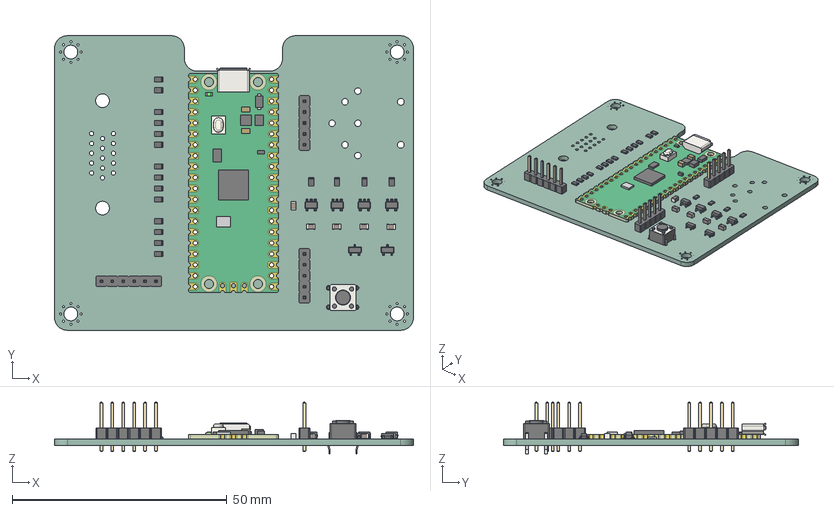
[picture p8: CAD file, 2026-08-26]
pcb/p2000t-vga-v1.step
83.6 x 68.6 x 12.0 mm
R_0805_2012Metric x 18
SOT-23-5 x 4
SOT-23 x 2
C_0805_2012Metric x 5
PinHeader_1x06_P254mm_Vertical
PinHeader_1x05_P254mm_Vertical x 2
SW_PUSH_6mm
RaspberryPi_Pico_Module_KiCad
p2000t-video-to-vga-adapter_PCB

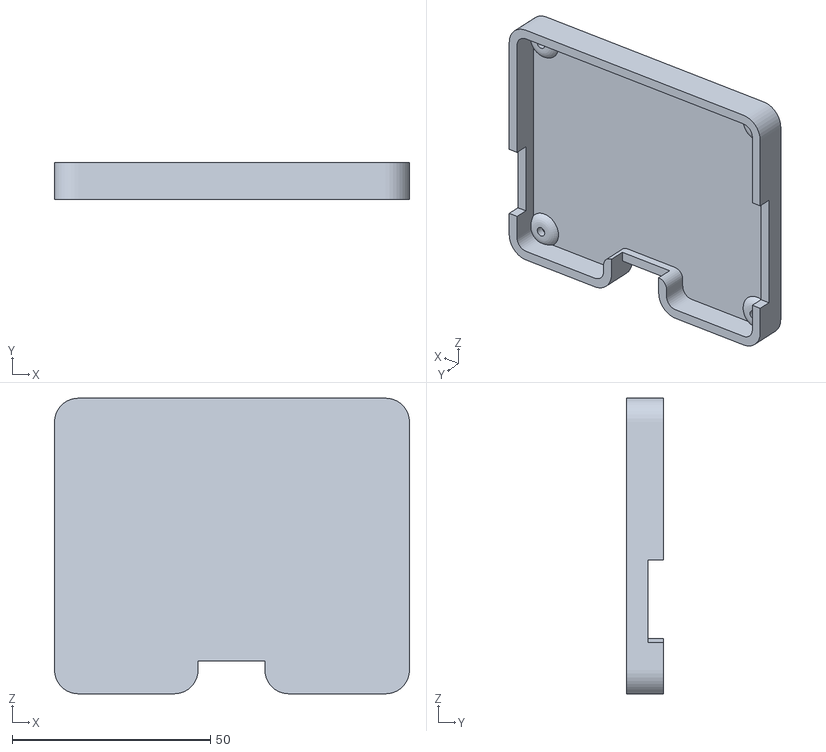
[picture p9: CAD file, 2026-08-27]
enclosure/bottom.stl
89.6 x 9.40 x 74.6

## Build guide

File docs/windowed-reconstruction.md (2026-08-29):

# Windowed 126 MHz reconstruction

Normal capture runs its PIO state machine at 126 MHz but retains two samples
per nominal 6 MHz source dot. The Pico 2 windowed engine retains three adjacent
126 MHz observations around each of those two positions. It therefore captures
six raw RGBS nibbles per source dot and reconstructs them into the existing
480x240 packed framebuffer.

Line synchronization remains clock-accurate in this path. The PIO uses a
hardware `WAIT` for the horizontal edge and then independently qualifies that
edge for 33 capture clocks. Do not replace this with a delayed polling jump:
that quantizes edge detection and manifests as temporal horizontal jitter.

The v0.4.1 engine DMA-captures a complete 172.8 KB high-resolution frame before
decoding it into the existing triple-buffered display path. Reconstruction is
therefore absent from the 64 us source scanline cadence. The DMA IRQ only
quiesces capture and records completion; core 0 then decodes one 720-byte
source line per main-loop service slice. Each slice writes 240 bytes and
returns, giving scanvideo on core 1 regular SRAM arbitration opportunities.
Its raw storage shares the logic analyzer's already-reserved SRAM; window
capture and a diagnostic session are mutually exclusive. The legacy two-tap
PIO program remains available and is restored at a source-frame boundary
whenever a non-window mode is selected.

## Policies

- `window-center` retains the middle sample from every three-tick window. It is
  the window-engine control and should resemble raw capture.
- `window-channel` takes the binary majority independently for the R, G, B,
  and sync inputs.
- `window-early` performs atomic color voting. Repeated colors win; when all
  three samples differ, it chooses the early endpoint.
- `window-late` uses the same atomic vote but chooses the late endpoint for an
  all-distinct transition.
- `window-confidence` uses `window-late` unchanged on one logical row parity.
  On the other parity it copies a paired half-dot only when that half's three
  samples are unanimous and the other half's samples are not. Two unanimous
  but different colors remain an edge, so the mode does not globally duplicate
  dots or erase stable geometry.

The early/late pair is deliberate. A measured blue-cyan-white sequence has no
three-sample mode, but cyan is known to be a one-tick intermediate color. Both
atomic policies suppress cyan while exposing whether choosing the pre-edge or
post-edge state gives the cleaner spatial result.

`sharp` does not use the window engine. It preserves the first normal tap and
only guards the second, unlike the legacy guarded mode which duplicates one
selected sample across both output pixels.

## Evidence and safety

Each streamed frame includes its reconstruction mode, capture engine, samples
per output, changed output samples, all-distinct windows, per-channel changes,
and a line-deadline flag. The Codex lab bridge stores these fields beside every
PNG and aggregates them in `result.json`.

The confidence guard is deliberately parity-aware. It applies on logical odd
rows, which correspond to physical even P2000T lines at the default first
visible line 57. The ordinary late policy remains active on logical even rows;
changing the first visible line also shifts this physical mapping.

Version 0.4.0 introduced the complete reconstruction-mode flash record while
continuing to read v0.3.x records. Hardware validation found that both the
lookup-based and direct line-rate six-tap reconstruction paths can starve the
independent VGA core's SRAM access: capture remains locked and USB frames are
correct, but the monitor receives black source scanlines.

Version 0.4.1 first tested complete-frame DMA followed by one monolithic batch
decode. USB continued to receive correct frames, but the VGA monitor lost
signal. Splitting that same decode into one-line service slices retained the
engineering image throughout 20- and 100-frame USB runs with zero deadline
misses. The window timing validator permits the resulting 60–80 ms cadence;
raw timing validation remains unchanged. The matched 100-frame confidence run
measured 149.19 robust instability ppm versus 142.67 ppm for raw. A second
whole-screen test exposed the more demanding blue-on-white and mosaic
transitions. On that page, `window-late`, phase 0, odd-line correction +1
reduced average changed pixels in every stable screen band while changing only
70 of 115,200 modal pixels. That balanced tuple is the Pico 2 v0.4.1 factory
default. Builds may explicitly disable the engine with
`-DP2000T_WINDOW_CAPTURE_ENABLED=OFF`.

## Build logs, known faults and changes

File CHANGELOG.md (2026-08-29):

# Changelog

Notable project changes are recorded here.

## 0.4.1 - Unreleased

- Replaced the monolithic Pico 2 six-tap decode with bounded one-line service
  slices. Live hardware retained VGA throughout repeated 100-frame USB runs
  with zero capture deadline misses.
- Set the Pico 2 factory tuple to `window-late`, phase 0, physical odd-line
  correction +1, and rate trim 0. Whole-screen validation reduced instability
  in the title, mosaic, blue-on-white text, white-on-blue text, and footer.
- Added a persistent USB factory reset which restores the validated capture
  tuple, palette, and artwork and immediately replaces the flash record.
- Added a 64-bit Pico capture-completion timestamp to USB stream protocol v4.
  The viewer accepts legacy v3 records and records both Pico and host times.
- Pico 1 retains its established raw phase-zero defaults.

## 0.4.0 - 2026-08-29

- Set the validated Pico 2 factory tuple to raw/two-tap reconstruction, phase
  -1, physical odd-line correction +1, and rate trim 0. A 100-frame validation
  retained sharp geometry while reducing robust temporal instability by about
  80% relative to phase 0 on the current test screen.
- Disabled continuous six-tap window reconstruction after hardware validation
  proved that its line-rate SRAM traffic can starve VGA scanout even while USB
  capture remains correct. Experimental saved window selections are migrated
  safely to raw on boot.
- Reject all-black saved palettes and substitute the firmware palette for an
  all-black live palette, preventing valid captured frames from being rendered
  as an undiagnosable black source image.
- Added reference-modal erased/filled/recolored pixel diagnostics and robust
  temporal logging which separates coherent high-change frames from the
  ordinary instability total.
- Raised raw diagnostic sampling from 126 MHz to 252 MHz without changing the
  production capture clock. Diagnostic records now use a guarded ACK/retry
  exchange so a CRC failure can be recovered without losing the requested
  burst, and the viewer preserves rejected records for investigation.
- Added direct diagnostic recording to the Codex lab bridge and an offline
  sampling-aperture analyzer for comparing reconstructed output against a
  captured reference image.

- Added a frame-boundary-switchable Pico 2 capture engine which records two
  three-tick 126 MHz windows per source dot into ping-pong scanline buffers and
  reconstructs the normal 480x240 framebuffer without another full-frame
  allocation. This remains engineering code and is not exposed by the stable
  build until its VGA memory contention is eliminated.
- Added sharp guarded reconstruction plus window-center, per-channel majority,
  atomic-early, atomic-late, and parity-aware confidence policies for measured
  engineering experiments. Stable Pico 2 operation defaults to raw.
- Extended the CRC-protected flash record to persist every reconstruction mode
  while retaining read compatibility with v0.3.x settings records.
- Added exact per-frame reconstruction telemetry to the USB stream and Codex
  lab results, including corrected/ambiguous samples, RGB channel corrections,
  active engine, and scanline-deadline failures.
- Fixed tagged release packaging so the generated SAA5050 cartridge binary is
  downloaded with the firmware/viewer artifacts before publishing a release.
### Added

- Pico 2 continuous USB capture streaming for 480×240 planar RGB111 frames,
  with per-frame CRC-32, raw/PackBits selection, non-blocking TinyUSB
  backpressure, and a target rate of 25 FPS.
- Minimal Qt 6 desktop capture viewer for Windows, Linux, and macOS, including
  native Pico CDC discovery, CRC validation, and lossless PNG screenshots.
- MSYS2/UCRT64 Windows viewer build, test, packaging, and release automation.
- P2000M-inspired NSIS graphical Windows installer with Program Files
  deployment, shortcuts, upgrade-aware identity, and a standard uninstaller.
- Viewer menus for application actions and live Pico 2 capture alignment and
  no-connection artwork configuration.
- Late-1990s Linux desktop-inspired icons for viewer connection,
  configuration, exit, and about actions.
- Interactive Pico 2 configuration dialog with exact capture-alignment
  spinners, artwork selection, and eight RGB444 color editors.
- CRC-protected flash persistence and structured USB request/state packets for
  saving and retrieving the complete adapter configuration.
- Tunable odd-source-line phase correction in 7.94 ns steps, available through
  the USB console, structured control protocol, and Pico 2 configuration UI.
- Tunable whole-line capture-rate correction in 1/256 PIO-divider steps, with
  live console and GUI control plus flash persistence.
- Automated viewer calibration sweeps over sample phase and horizontal rate
  trim, with acknowledged setting changes, configurable settling, repeated
  PNG captures, CSV/session metadata, cancellation, and settings restoration.
- Persisted raw/guarded-second-tap SAA5050 source-dot reconstruction, applied
  frame-atomically to VGA and identically to Pico 2 USB captures, with console
  and GUI controls. The mode was selected from offline temporal analysis of a
  1,250-frame calibration sweep.
- Guarded reconstruction now rejects a second-tap color which matches neither
  its own first tap nor the following dot's first tap, suppressing the
  one-clock RGB transition states measured by high-resolution diagnostics.
- Pico 2 high-resolution diagnostic recording with a full-frame 63 MHz CSYNC
  trace, repeated sync-triggered 126 MHz raw RGBS bursts, capture-duration
  overrun detection, CRC-protected lossless records, viewer session recording,
  and a reproducible analysis utility.
- Unattended engineering-screen autotuning in the viewer. It exhaustively
  searches phase and capture-rate trim, independently tunes physical odd-line
  phase, validates the winner, keeps reconstruction raw to prevent blur from
  gaming the score, and records labeled frames, modal PNGs, per-parity temporal
  and spatial metrics, CSV logs, and a machine-readable JSON recommendation.
- Invisible Windows Codex lab agent, shared bridge support in the viewer, and
  a WSL command-line client.
  Codex can directly query adapter state, apply acknowledged non-persistent
  timing/reconstruction settings, capture and score repeated frames, inspect
  the resulting PNG evidence, adapt subsequent experiments, or cancel and
  restore an experiment, explicitly save a chosen tuple after acknowledgement,
  or shut down the agent through an atomic JSON request/response directory.

### Changed

- Calibration sweeps now request an explicit complete setting state, retry a
  missing acknowledgement with a bounded timeout, report mismatched values,
  and remember the last selected analysis parent directory.
- Capture PIO and DMA are quiesced before a flash settings write, and
  acquisition restarts at a clean frame boundary. This prevents flash-safe
  interrupt pauses from corrupting or stopping capture.
- Capture-buffer ownership now permits a short-lived Pico 2 USB reader without
  exposing a buffer that DMA may overwrite or changing the Pico/RP2040 memory
  footprint.
- The desktop viewer duplicates every source scanline for the correct 480×480
  square-pixel display and PNG geometry.
- USB state records now identify signal loss and the no-connection artwork
  actually displayed by the VGA core without transferring stale pixels.
- The viewer now reproduces the complete selected 640×480 no-connection VGA
  screen from embedded RGB444 artwork and a shared pixel-exact overlay layout.
- A transparent retro-computing application icon based on the real P2000T,
  DIN6, and VGA connector silhouettes is embedded in the Qt application and
  the multi-resolution Windows executable resources.
- Windows CI now validates the installer archive and smoke-tests a fresh
  install, same-directory upgrade, and complete uninstall on every commit.
- The viewer now attempts to connect to the first detected Pico USB port at
  startup, and Pico 2 firmware accepts silent configuration commands without
  interrupting its binary screen stream.
- Source-color lookup tables are triple-buffered and adopted at VGA frame
  boundaries so palette changes cannot split a frame between two palettes.
- Viewer configuration edits are now applied to the connected Pico 2
  immediately; flash persistence remains an explicit action.
- The on-board Pico LED now breathes slowly while seeking a P2000T signal and
  blinks at 0.5-second intervals while valid input is present.
- The first captured line now compensates for its distinct sync-entry path
  without the previous one-PIO-tick phase discrepancy.
- Capture timing commands are rebuilt outside the shared frame-buffer lock so
  the VGA core cannot be held off long enough to emit a missing scanline.

## 0.2.0 - 2026-08-27

### Added

- Green-phosphor, synthwave, and amber-circuit no-connection artwork, selectable
  at runtime with USB commands `1`, `2`, and `3`.
- Automatic CMake downloads for the pinned Pico SDK and pico-extras releases.

### Changed

- No-connection artwork now uses a timing-safe 16-color RGB444 indexed
  pipeline with one SRAM palette lookup per pair of pixels.
- Artwork selection is adopted atomically at VGA frame boundaries to prevent
  tearing.
- Linux build requirements and artwork controls are documented in the README.
- GitHub Actions uses the same self-contained CMake dependency setup as local
  builds.

## 0.1.1 - 2026-08-26

### Added

- P2000M-style signal-loss status screen.
- GitHub Actions builds and downloadable artifacts for Pico and Pico 2.
- Automatic GitHub Releases with stable Pico and Pico 2 UF2 filenames when a
  tag is pushed.
- Pico 2 RP2350 build support using the experimental 252 MHz clock setup.

### Changed

- Board selection is now controlled with `PICO_BOARD` in a separate CMake
  build directory.
- Source-frame and no-signal rendering are isolated in a dedicated,
  SRAM-resident renderer module.
- Firmware functions, parameters, constants, state, and public data structures
  now have Doxygen documentation.
- Frame-buffer sequence comparisons remain correct across 32-bit counter
  rollover.

### Removed

- Unused raw-pixel accessor, frame-byte constant, and lowercase font
  normalization left over from earlier capture experiments.

## 0.1.0 - 2026-08-26

### Added

- 480×240 raw RGBS capture with two samples per 6 MHz source dot.
- 640×480 at 60 Hz RGB444 VGA output with vertical line doubling.
- Triple-buffered full-frame capture and frame-boundary display updates.
- CSYNC holdoff and pulse qualification for improved line stability.
- USB status and timing-adjustment commands.
- P2000T SAA5050 screen-test cartridge.

### Changed

- Sample phase 0 is the default.

### Removed

- Obsolete standalone signal-probe firmware.

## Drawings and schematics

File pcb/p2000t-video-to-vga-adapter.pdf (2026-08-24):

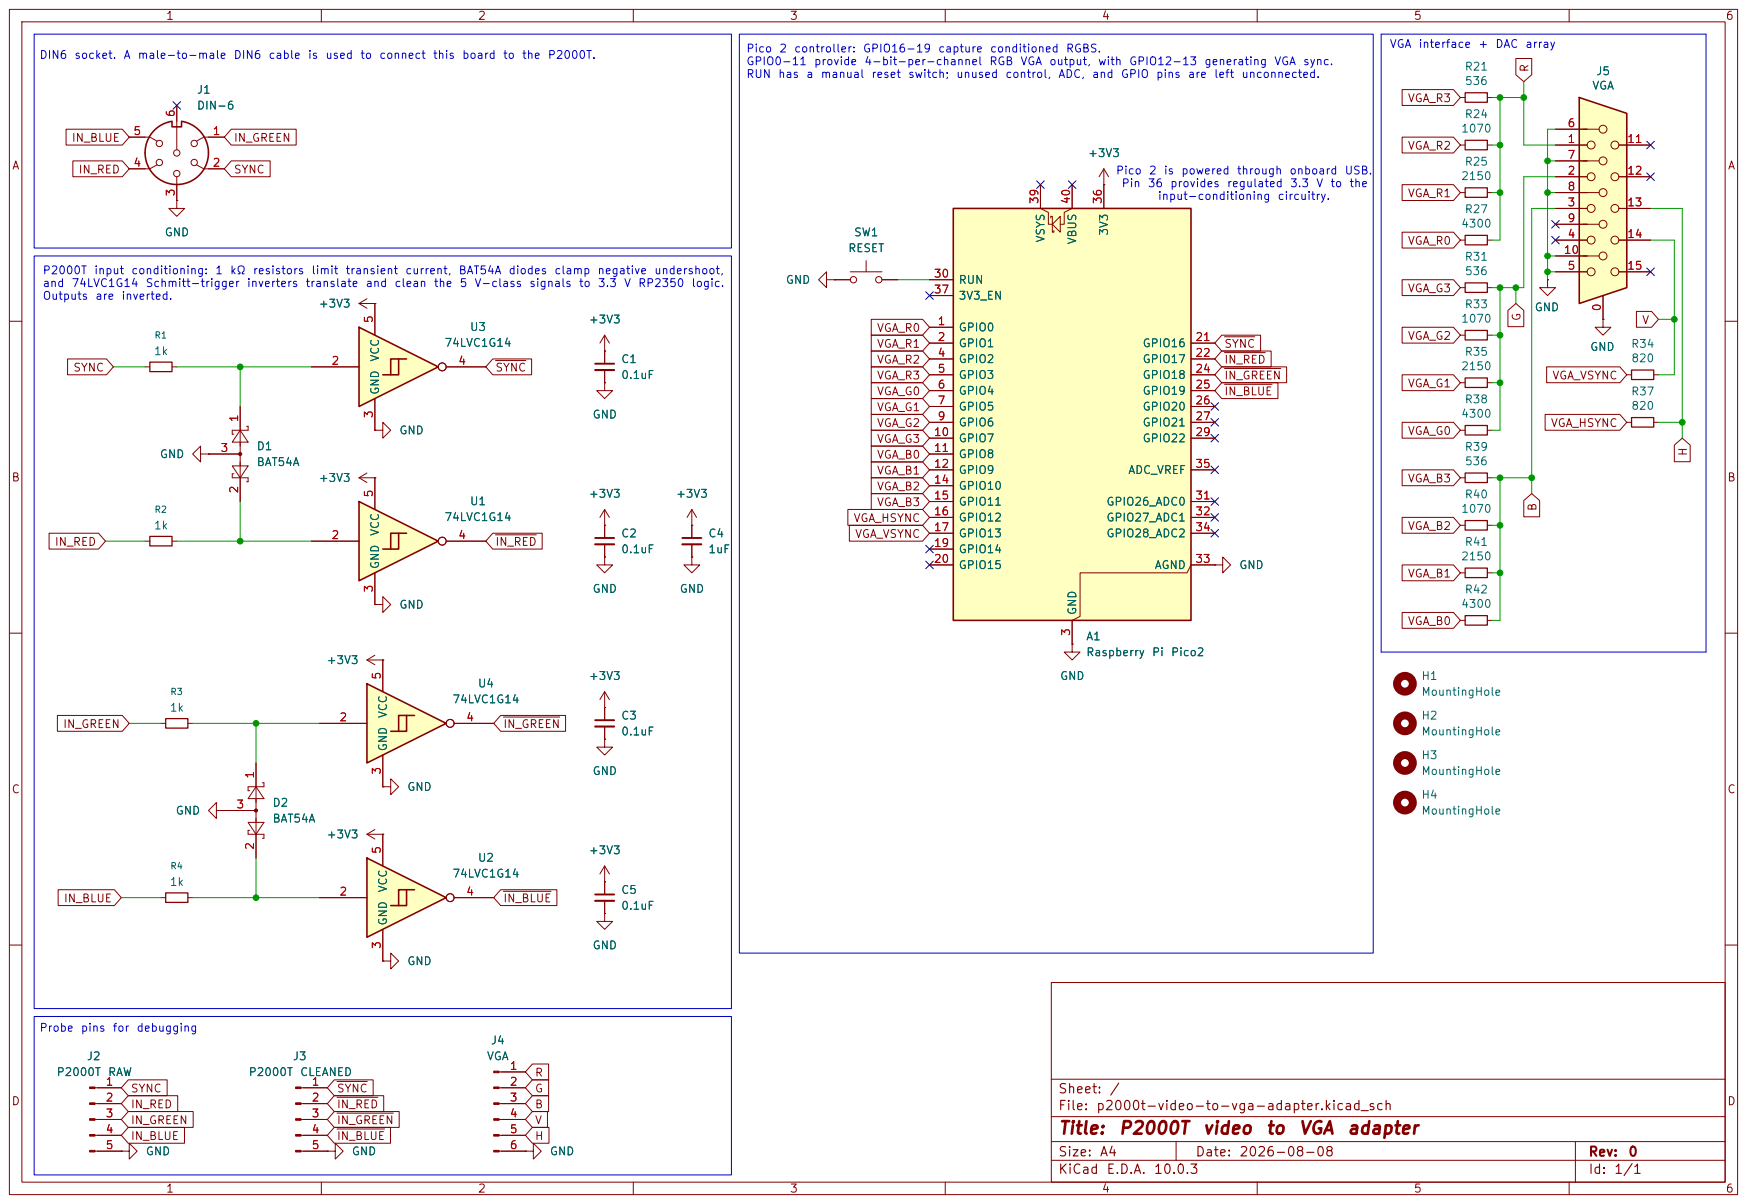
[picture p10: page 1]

DIN6 socket. A male-to-male DIN6 cable is used to connect this board to the P2000T. P2000T input conditioning: 1 kΩ resistors limit transient current, BAT54A diodes clamp negative undershoot, and 74LVC1G14 Schmitt-trigger inverters translate and clean the 5 V-class signals to 3.3 V RP2350 logic.

Probe pins for debugging

Sheet: /
File: p2000t-video-to-vga-adapter.kicad_sch
Title: P2000T video to VGA adapter

Size: A4 | Rev: 0
KiCad E.D.A. 10.0.3 | Id: 1/1

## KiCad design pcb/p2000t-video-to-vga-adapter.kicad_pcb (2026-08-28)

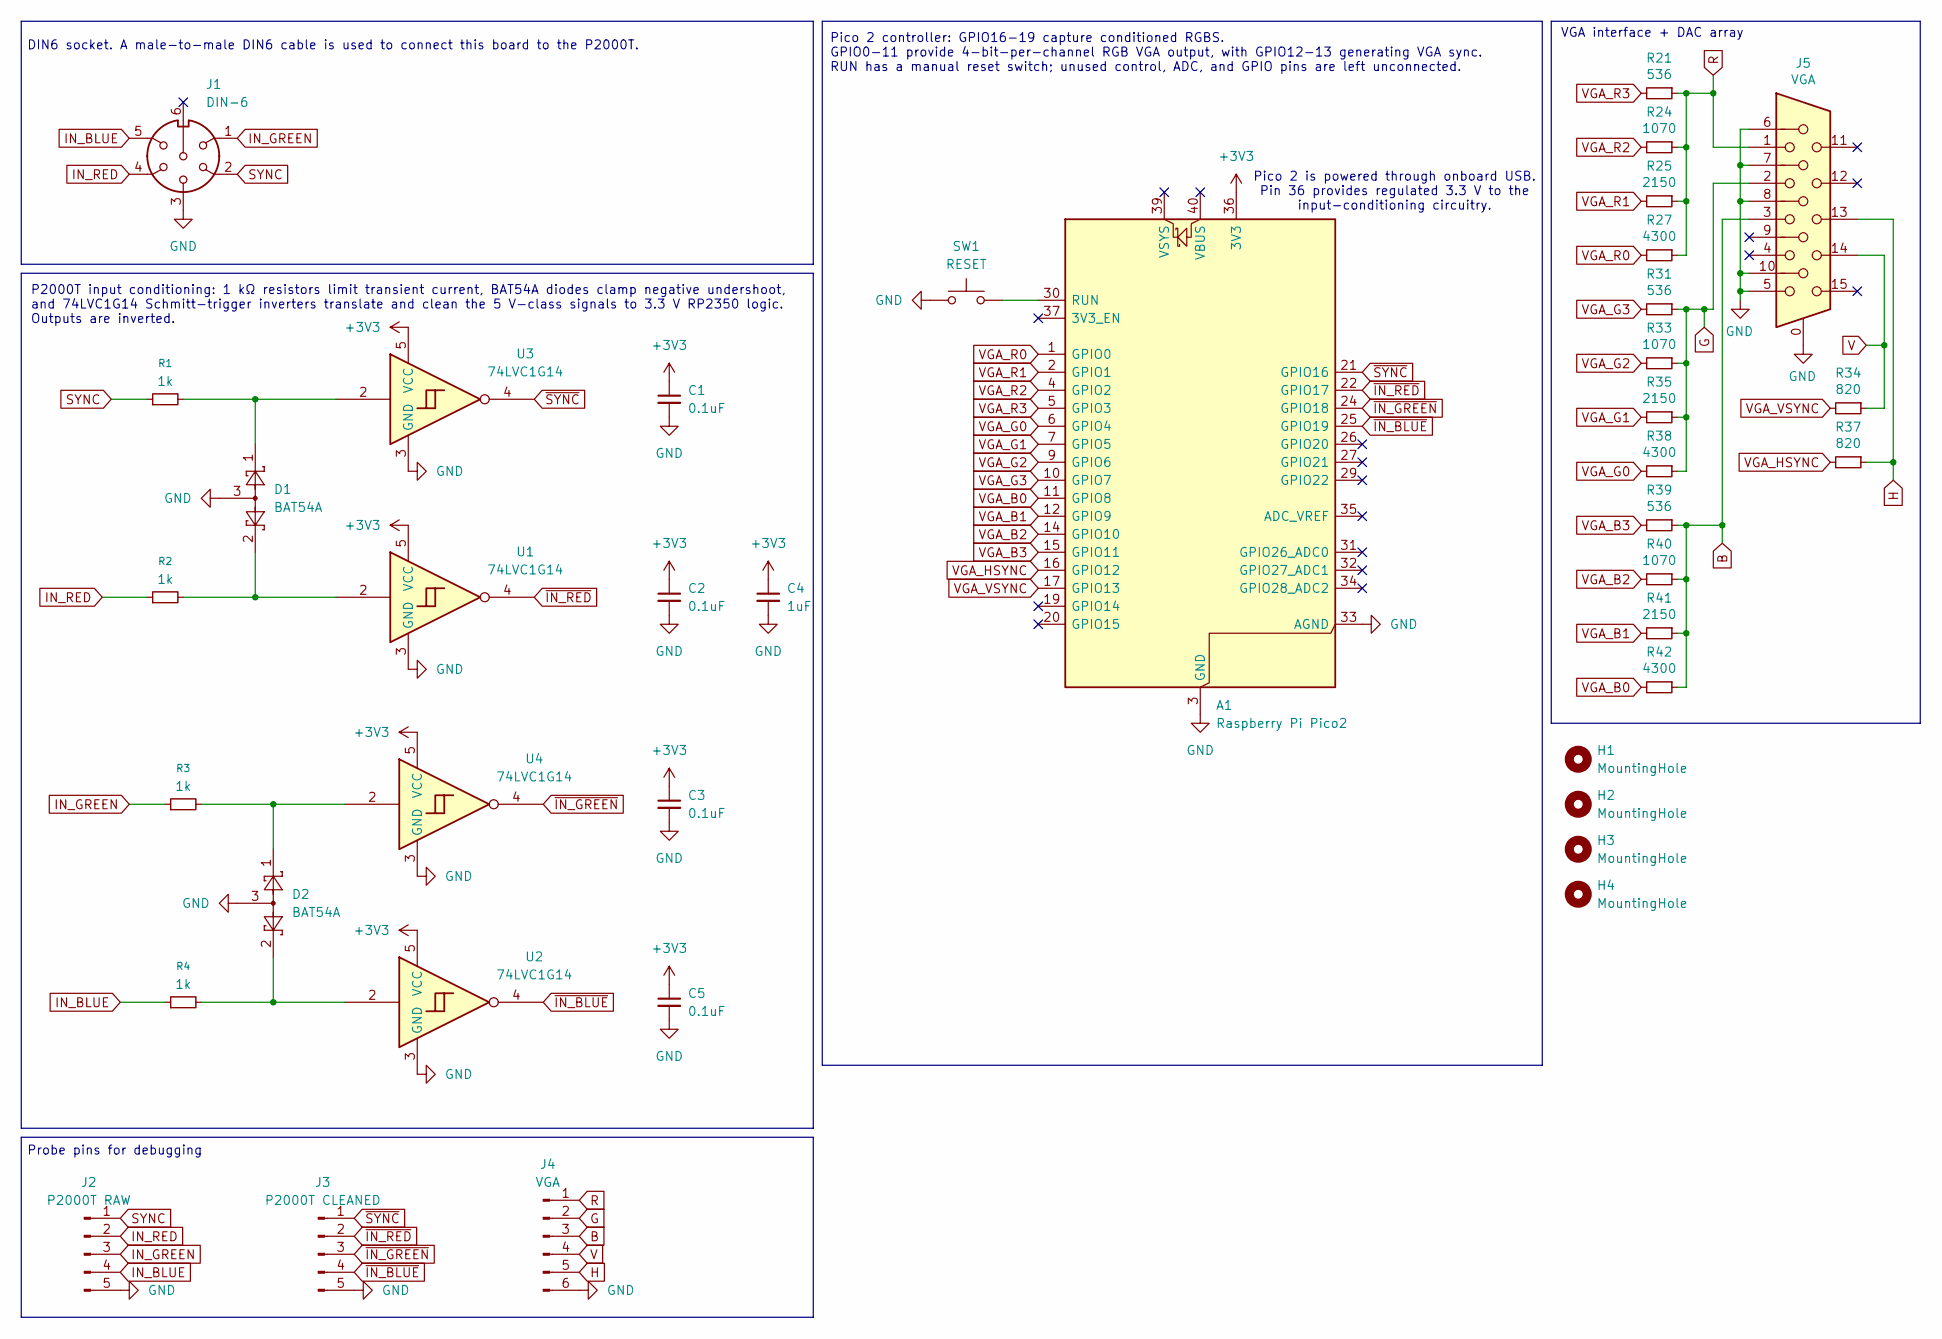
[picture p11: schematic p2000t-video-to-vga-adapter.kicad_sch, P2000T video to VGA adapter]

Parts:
A1: Raspberry Pi Pico2; RaspberryPi_Pico_Common_Unspecified
C1, C2, C3, C5: 0.1uF; C_0805_2012Metric_Pad1.18x1.45mm_HandSolder; LCSC Part # C28233
C4: 1uF; C_0805_2012Metric_Pad1.18x1.45mm_HandSolder; LCSC Part # C28323
D1, D2: BAT54A; SOT-23; LCSC Part # C130910
H1, H2, H3, H4: MountingHole; MountingHole_3.2mm_M3_Pad_Via
J1: DIN-6; SDF-60J
J2: P2000T RAW; PinHeader_1x05_P2.54mm_Vertical
J3: P2000T CLEANED; PinHeader_1x05_P2.54mm_Vertical
J4: VGA; PinHeader_1x06_P2.54mm_Vertical
J5: VGA
R1, R2, R3, R4: 1k; R_0805_2012Metric_Pad1.20x1.40mm_HandSolder; LCSC Part # C17513
R21, R31, R39: 536; R_0805_2012Metric_Pad1.20x1.40mm_HandSolder; LCSC Part # C343952
R24, R33, R40: 1070; R_0805_2012Metric_Pad1.20x1.40mm_HandSolder; LCSC Part # C865249
R25, R35, R41: 2150; R_0805_2012Metric_Pad1.20x1.40mm_HandSolder; LCSC Part # C515726
R27, R38, R42: 4300; R_0805_2012Metric_Pad1.20x1.40mm_HandSolder; LCSC Part # C473294
R34, R37: 820; R_0805_2012Metric_Pad1.20x1.40mm_HandSolder; LCSC Part # C865664
SW1: RESET; SW_PUSH_6mm
U1, U2, U3, U4: 74LVC1G14; SOT-23-5_HandSoldering; LCSC Part # C131093

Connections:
+3V3: A1.36 (3V3), C1.1, C2.1, C3.1, C4.1, C5.1, U1.5 (VCC), U2.5 (VCC), U3.5 (VCC), U4.5 (VCC)
B: J4.3, J5.3, R39.1, R40.1, R41.1, R42.1
G: J4.2, J5.2, R31.1, R33.1, R35.1, R38.1
GND: A1.3 (GND), A1.8 (GND), A1.13 (GND), A1.18 (GND), A1.23 (GND), A1.28 (GND), A1.33 (AGND), A1.38 (GND), C1.2, C2.2, C3.2, C4.2, C5.2, D1.3, D2.3, J1.3, J2.5, J3.5, J4.6, J5.0, J5.5, J5.6, J5.7, J5.8, J5.10, SW1.1, U1.3 (GND), U2.3 (GND), U3.3 (GND), U4.3 (GND)
H: J4.5, J5.13, R37.1
IN_BLUE: J1.5, J2.4, R4.1
IN_GREEN: J1.1, J2.3, R3.1
IN_RED: J1.4, J2.2, R2.1
unnamed: A1.30 (RUN), SW1.2
unnamed: D1.1, R1.2, U3.2
unnamed: D1.2, R2.2, U1.2
unnamed: D2.1, R3.2, U4.2
unnamed: D2.2, R4.2, U2.2
R: J4.1, J5.1, R21.1, R24.1, R25.1, R27.1
SYNC: J1.2, J2.1, R1.1
V: J4.4, J5.14, R34.1
VGA_B0: A1.11 (GPIO8), R42.2
VGA_B1: A1.12 (GPIO9), R41.2
VGA_B2: A1.14 (GPIO10), R40.2
VGA_B3: A1.15 (GPIO11), R39.2
VGA_G0: A1.6 (GPIO4), R38.2
VGA_G1: A1.7 (GPIO5), R35.2
VGA_G2: A1.9 (GPIO6), R33.2
VGA_G3: A1.10 (GPIO7), R31.2
VGA_HSYNC: A1.16 (GPIO12), R37.2
VGA_R0: A1.1 (GPIO0), R27.2
VGA_R1: A1.2 (GPIO1), R25.2
VGA_R2: A1.4 (GPIO2), R24.2
VGA_R3: A1.5 (GPIO3), R21.2
VGA_VSYNC: A1.17 (GPIO13), R34.2
~IN_BLUE: A1.25 (GPIO19), J3.4, U2.4
~IN_GREEN: A1.24 (GPIO18), J3.3, U4.4
~IN_RED: A1.22 (GPIO17), J3.2, U1.4
~SYNC: A1.21 (GPIO16), J3.1, U3.4

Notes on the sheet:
VGA interface + DAC array
DIN6 socket. A male-to-male DIN6 cable is used to connect this board to the P2000T.
P2000T input conditioning: 1 kΩ resistors limit transient current, BAT54A diodes clamp negative undershoot, and 74LVC1G14 Schmitt-trigger inverters translate and clean the 5 V-class signals to 3.3 V RP2350 logic. Outputs are inverted.
Pico 2 controller: GPIO16-19 capture conditioned RGBS. GPIO0-11 provide 4-bit-per-channel RGB VGA output, with GPIO12-13 generating VGA sync. RUN has a manual reset switch; unused control, ADC, and GPIO pins are left unconnected.
Pico 2 is powered through onboard USB. Pin 36 provides regulated 3.3 V to the input-conditioning circuitry.
Probe pins for debugging

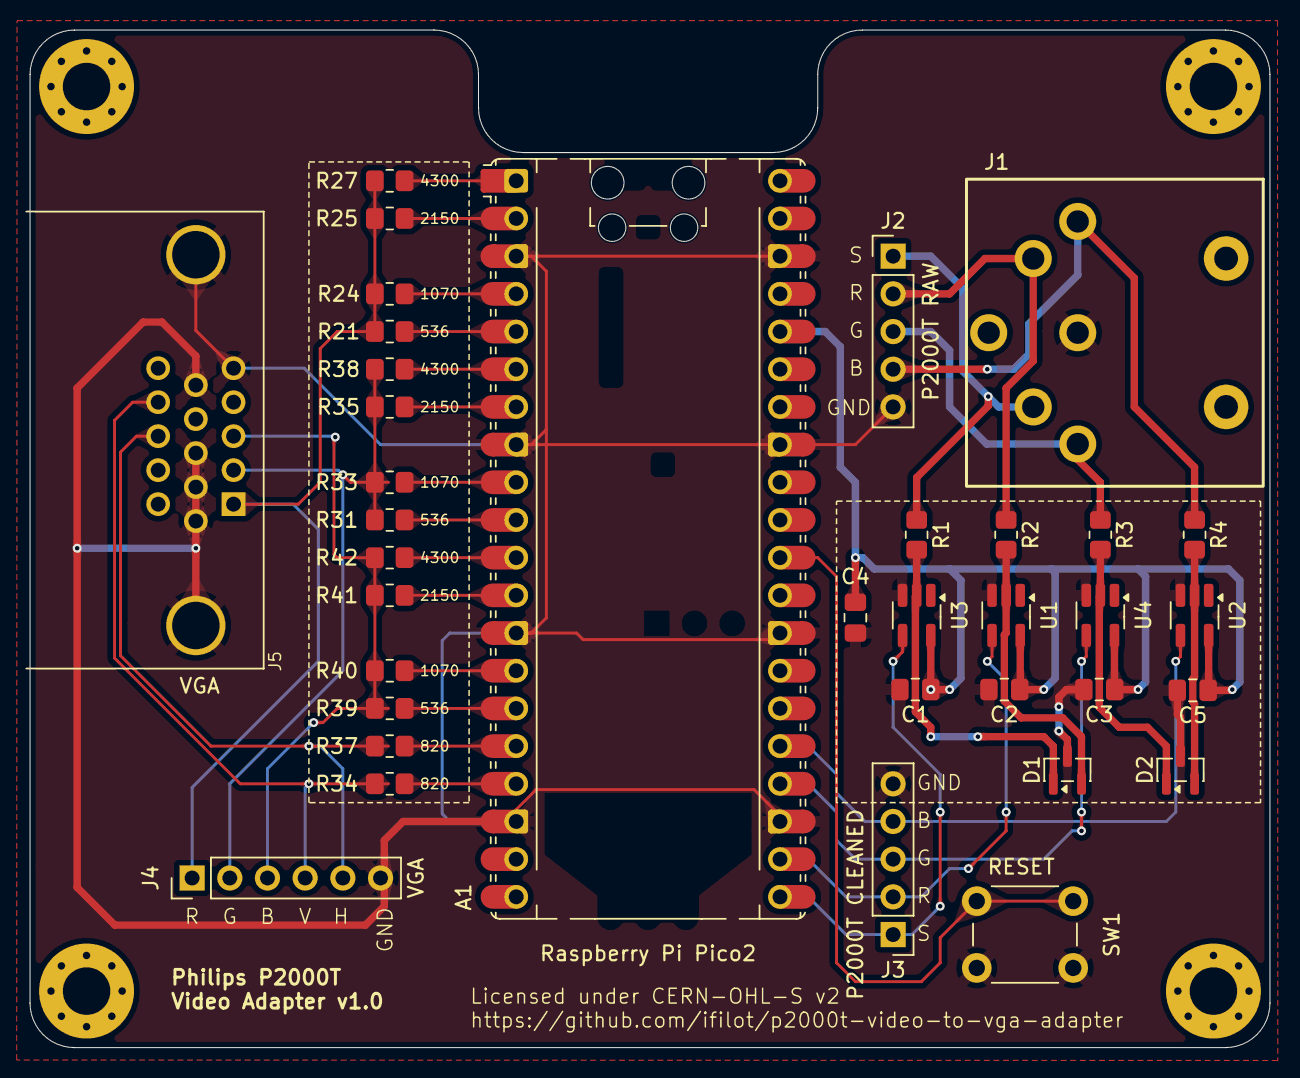
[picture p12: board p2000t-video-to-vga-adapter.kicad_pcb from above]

Board: 2 copper layers, 83.6 x 68.6 mm, 40 parts (0 on the bottom side), 34 nets.

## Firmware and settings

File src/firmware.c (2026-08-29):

/*
 * SPDX-FileCopyrightText: 2026 Ivo Filot <ivo@ivofilot.nl>
 * SPDX-License-Identifier: GPL-3.0-or-later
 */

/**
 * @file firmware.c
 * @brief P2000T RGBS capture, VGA orchestration, and USB control interface.
 */

#include <inttypes.h>
#include <stdbool.h>
#include <stdint.h>
#include <stdio.h>
#include <string.h>

#include "hardware/clocks.h"
#include "hardware/pwm.h"
#include "hardware/vreg.h"
#include "p2000t_capture.h"
#include "p2000t_control_protocol.h"
#include "p2000t_settings.h"
#include "p2000t_video_renderer.h"
#include "pico/flash.h"
#include "pico/multicore.h"
#include "pico/scanvideo.h"
#include "pico/stdio_usb.h"
#include "pico/stdlib.h"

#if defined(PICO_RP2350) && PICO_RP2350
#include "p2000t_diagnostic_protocol.h"
#include "p2000t_diagnostics.h"
#include "p2000t_stream_protocol.h"
#include "p2000t_usb_stream.h"
#endif

#if defined(PICO_RP2040) && PICO_RP2040
/** Human-readable processor name included in the USB banner. */
#define P2000T_PROCESSOR_NAME "RP2040 / Pico 1"
#elif defined(PICO_RP2350) && PICO_RP2350
/** Human-readable processor name included in the USB banner. */
#define P2000T_PROCESSOR_NAME "RP2350 / Pico 2"
#else
#error "The P2000T VGA firmware supports only Pico and Pico 2"
#endif

/** Firmware clock, voltage, and inter-core synchronization constants. */
enum {
    SYSTEM_CLOCK_KHZ = 252000,        /**< Overclocked system frequency. */
    SYSTEM_CORE_VOLTAGE_MV = 1300,    /**< Core voltage used at 252 MHz. */
    VGA_READY_MAGIC = 0x56474154,     /**< Core-1 VGA-ready FIFO token. */
    STATUS_LED_MAX_LEVEL = 255,       /**< Maximum logical brightness. */
    STATUS_LED_PWM_WRAP = 65535,      /**< Full 16-bit PWM brightness range. */
    STATUS_LED_PWM_CLOCK_DIVIDER = 8, /**< About 480 Hz at 252 MHz. */
    STATUS_LED_SERVICE_INTERVAL_US = 5000,  /**< 200 Hz LED update rate. */
    STATUS_LED_ACTIVE_INTERVAL_US = 500000, /**< Connected on/off interval. */
    STATUS_LED_SEEK_CYCLE_US = 2500000, /**< Complete seeking breath cycle. */
    STATUS_LED_SEEK_HALF_CYCLE_US = STATUS_LED_SEEK_CYCLE_US / 2,
};

_Static_assert(P2000T_VGA_RENDER_WIDTH *P2000T_VGA_HORIZONTAL_SCALE ==
                   P2000T_VGA_TIMING_WIDTH,
               "Scanvideo must render all 640 VGA pixels directly");
_Static_assert(P2000T_VGA_RENDER_HEIGHT *P2000T_VGA_VERTICAL_SCALE ==
                   P2000T_VGA_TIMING_HEIGHT,
               "Each captured source line must produce two VGA lines");
_Static_assert((unsigned)P2000T_CAPTURE_HEIGHT ==
                   (unsigned)P2000T_VGA_RENDER_HEIGHT,
               "Each source line must map to one logical scanvideo line");
_Static_assert((int)P2000T_MIN_ODD_LINE_PHASE ==
                       (int)P2000T_CONTROL_MIN_ODD_LINE_PHASE &&
                   (int)P2000T_MAX_ODD_LINE_PHASE ==
                       (int)P2000T_CONTROL_MAX_ODD_LINE_PHASE &&
                   (int)P2000T_DEFAULT_ODD_LINE_PHASE ==
                       (int)P2000T_CONTROL_DEFAULT_ODD_LINE_PHASE,
               "Capture and control odd-line phase ranges must match");
_Static_assert((int)P2000T_MIN_SAMPLE_RATE_TRIM ==
                       (int)P2000T_CONTROL_MIN_SAMPLE_RATE_TRIM &&
                   (int)P2000T_MAX_SAMPLE_RATE_TRIM ==
                       (int)P2000T_CONTROL_MAX_SAMPLE_RATE_TRIM &&
                   (int)P2000T_DEFAULT_SAMPLE_RATE_TRIM ==
                       (int)P2000T_CONTROL_DEFAULT_SAMPLE_RATE_TRIM,
               "Capture and control sample-rate trim ranges must match");
#if defined(PICO_RP2350) && PICO_RP2350
_Static_assert((unsigned)P2000T_NO_SIGNAL_GREEN_PHOSPHOR ==
                       (unsigned)P2000T_STREAM_ARTWORK_GREEN_PHOSPHOR &&
                   (unsigned)P2000T_NO_SIGNAL_SYNTHWAVE ==
                       (unsigned)P2000T_STREAM_ARTWORK_SYNTHWAVE &&
                   (unsigned)P2000T_NO_SIGNAL_AMBER_CIRCUIT ==
                       (unsigned)P2000T_STREAM_ARTWORK_AMBER_CIRCUIT &&
                   (unsigned)P2000T_NO_SIGNAL_ARTWORK_COUNT ==
                       (unsigned)P2000T_STREAM_ARTWORK_COUNT,
               "USB artwork identifiers must match the VGA renderer");
#endif

/** Standard 640x480, nominal 60 Hz VGA at a 25.2 MHz pixel clock. */
static const scanvideo_timing_t vga_timing_640x480_60 = {
    .clock_freq = 25200000,
    .h_active = P2000T_VGA_TIMING_WIDTH,
    .v_active = P2000T_VGA_TIMING_HEIGHT,
    .h_front_porch = 16,
    .h_pulse = 96,
    .h_total = 800,
    .h_sync_polarity = 1,
    .v_front_porch = 10,
    .v_pulse = 2,
    .v_total = 525,
    .v_sync_polarity = 1,
    .enable_clock = 0,
    .clock_polarity = 0,
    .enable_den = 0,
};

/** Logical scanvideo mode that vertically doubles the 240-line source. */
static const scanvideo_mode_t firmware_vga_mode = {
    .default_timing = &vga_timing_640x480_60,
    .pio_program = &video_24mhz_composable,
    .width = P2000T_VGA_RENDER_WIDTH,
    .height = P2000T_VGA_RENDER_HEIGHT,
    .xscale = P2000T_VGA_HORIZONTAL_SCALE,
    .yscale = P2000T_VGA_VERTICAL_SCALE,
    .yscale_denominator = 1,
};

/** Frame and scanline state owned exclusively by the VGA core. */
typedef struct {
    int buffer_index;      /**< Currently displayed capture buffer. */
    const uint32_t *frame; /**< Packed frame currently being read. */
    bool signal_present;   /**< Signal decision fixed per VGA frame. */
    p2000t_no_signal_artwork_t
        no_signal_artwork;          /**< Artwork fixed per VGA frame. */
    uint32_t previous_scanline_id;  /**< Last scanvideo identifier observed. */
    bool have_previous_scanline_id; /**< Whether the previous ID is valid. */
} vga_display_state_t;

/** Cross-core diagnostic counters updated by the VGA core. */
typedef struct {
    volatile uint32_t displayed_sequence; /**< Current source-frame sequence. */
    volatile uint32_t generated_frames;   /**< VGA frames started. */
    volatile uint32_t source_frame_swaps; /**< New source frames adopted. */
    volatile uint32_t repeated_frames; /**< VGA frames reusing source data. */
    volatile uint32_t
        signal_lost_frames;             /**< VGA frames with no valid input. */
    volatile uint32_t scanline_id_gaps; /**< Non-contiguous scanline IDs. */
    volatile uint32_t
        signal_present; /**< Signal state used by current VGA frame. */
    volatile uint32_t
        no_signal_artwork; /**< Artwork used by current VGA frame. */
} vga_statistics_t;

/** VGA-core-owned display state, initialized without a captured frame. */
static vga_display_state_t display_state = {
    .buffer_index = -1,
    .no_signal_artwork = P2000T_NO_SIGNAL_ARTWORK_DEFAULT,
};

/** Diagnostics shared atomically between the VGA and control cores. */
static vga_statistics_t vga_statistics = {
    .no_signal_artwork = P2000T_NO_SIGNAL_ARTWORK_DEFAULT,
};

/** USB-selected artwork adopted by the VGA core at its next frame boundary. */
static volatile uint32_t requested_no_signal_artwork =
    P2000T_NO_SIGNAL_ARTWORK_DEFAULT;

/** Active and last successfully persisted user configuration. */
static p2000t_settings_t current_settings;
static p2000t_settings_t stored_settings;
static unsigned stored_reconstruction_mode;
static bool stored_settings_valid;
static bool settings_save_failed;
/** Live reconstruction is stored separately from the legacy packed bit. */
static unsigned current_reconstruction_mode =
    P2000T_CONTROL_DEFAULT_SAMPLE_RECONSTRUCTION;

#if defined(PICO_RP2350) && PICO_RP2350
enum {
    FIRMWARE_DEFAULT_SAMPLE_PHASE = P2000T_CONTROL_PICO2_DEFAULT_PHASE,
    FIRMWARE_DEFAULT_ODD_LINE_PHASE =
        P2000T_CONTROL_PICO2_DEFAULT_ODD_LINE_PHASE,
};
#else
enum {
    FIRMWARE_DEFAULT_SAMPLE_PHASE = P2000T_CONTROL_DEFAULT_PHASE,
    FIRMWARE_DEFAULT_ODD_LINE_PHASE = P2000T_CONTROL_DEFAULT_ODD_LINE_PHASE,
};
#endif

static const char *sample_reconstruction_name(unsigned reconstruction);

/** On-board LED state, owned exclusively by the control core. */
static uint64_t status_led_state_started_us;
static uint64_t status_led_next_service_us;
static unsigned status_led_previous_level = STATUS_LED_MAX_LEVEL + 1u;
static bool status_led_previous_signal_present;
static bool status_led_state_initialized;

/** Incremental structured-control packet receiver. */
static uint8_t control_packet[P2000T_CONTROL_PACKET_SIZE];
static unsigned control_packet_offset;

_Static_assert(
    (int)P2000T_CONTROL_MIN_VERTICAL ==
            (int)P2000T_MIN_FIRST_VISIBLE_SCANLINE &&
        (int)P2000T_CONTROL_MAX_VERTICAL ==
            (int)P2000T_MAX_FIRST_VISIBLE_SCANLINE &&
        (int)P2000T_CONTROL_MIN_PHASE == (int)P2000T_MIN_SAMPLE_PHASE &&
        (int)P2000T_CONTROL_MAX_PHASE == (int)P2000T_MAX_SAMPLE_PHASE &&
        (int)P2000T_CONTROL_MIN_HORIZONTAL ==
            (int)P2000T_MIN_HORIZONTAL_OFFSET &&
        (int)P2000T_CONTROL_MAX_HORIZONTAL == (int)P2000T_MAX_HORIZONTAL_OFFSET,
    "Control protocol limits must match capture limits");

/**
 * @brief Increment a diagnostic counter owned exclusively by the VGA core.
 *
 * The control core performs aligned atomic loads, while the VGA core remains
 * the sole writer. Avoiding a read-modify-write atomic here also avoids the
 * RP2040's out-of-line atomic helper in a deadline-sensitive path.
 *
 * @param counter VGA-core-owned counter to increment.
 */
static inline void increment_counter(volatile uint32_t *counter) {
    ++*counter;
}

/**
 * @brief Atomically load a cross-core diagnostic value.
 *
 * @param value Value to read using relaxed memory ordering.
 * @return Consistent 32-bit snapshot of the value.
 */
static inline uint32_t load_statistic(const volatile uint32_t *value) {
    return __atomic_load_n(value, __ATOMIC_RELAXED);
}

/**
 * @brief Atomically store a cross-core diagnostic value.
 *
 * @param destination Value to update using relaxed memory ordering.
 * @param value New value to store.
 */
static inline void store_statistic(volatile uint32_t *destination,
                                   uint32_t value) {
    __atomic_store_n(destination, value, __ATOMIC_RELAXED);
}

/** @brief Set the on-board LED PWM level, respecting active-low boards. */
static void status_led_set_level(unsigned level) {
    hard_assert(level <= STATUS_LED_MAX_LEVEL);
    if (level == status_led_previous_level) {
        return;
    }
    status_led_previous_level = level;
#if defined(PICO_DEFAULT_LED_PIN_INVERTED) && PICO_DEFAULT_LED_PIN_INVERTED
    level = STATUS_LED_MAX_LEVEL - level;
#endif
    pwm_set_gpio_level(
        PICO_DEFAULT_LED_PIN,
        (uint16_t)(level * (STATUS_LED_PWM_WRAP / STATUS_LED_MAX_LEVEL)));
}

/** @brief Configure low-frequency hardware PWM for the on-board LED. */
static void status_led_initialize(void) {
    gpio_set_function(PICO_DEFAULT_LED_PIN, GPIO_FUNC_PWM);
    const unsigned slice = pwm_gpio_to_slice_num(PICO_DEFAULT_LED_PIN);
    pwm_config config = pwm_get_default_config();
    pwm_config_set_clkdiv_int(&config, STATUS_LED_PWM_CLOCK_DIVIDER);
    pwm_config_set_wrap(&config, STATUS_LED_PWM_WRAP);
    pwm_init(slice, &config, true);
    status_led_set_level(0u);
    status_led_next_service_us = time_us_64();
}

/**
 * @brief Update the on-board LED for seeking or active capture.
 *
 * A credible P2000T signal produces a 0.5-second on/off activity blink. While
 * seeking, a gamma-shaped 2.5-second triangle wave controls a quiet 480 Hz
 * hardware PWM carrier. Brightness calculations remain capped at 200 Hz,
 * independently of the much faster USB streaming loop.
 *
 * @param signal_present Whether the VGA core has adopted a valid input signal.
 */
static void status_led_service(bool signal_present) {
    const uint64_t now_us = time_us_64();
    if (now_us < status_led_next_service_us) {
        return;
    }
    status_led_next_service_us = now_us + STATUS_LED_SERVICE_INTERVAL_US;

    if (!status_led_state_initialized ||
        signal_present != status_led_previous_signal_present) {
        status_led_state_initialized = true;
        status_led_previous_signal_present = signal_present;
        status_led_state_started_us = now_us;
    }

    const uint32_t elapsed_us =
        (uint32_t)(now_us - status_led_state_started_us);
    unsigned level;
    if (signal_present) {
        level = ((elapsed_us / STATUS_LED_ACTIVE_INTERVAL_US) & 1u) == 0u
                    ? STATUS_LED_MAX_LEVEL
                    : 0u;
    } else {
        const uint32_t phase_us = elapsed_us % STATUS_LED_SEEK_CYCLE_US;
        const uint32_t ramp_us = phase_us <= STATUS_LED_SEEK_HALF_CYCLE_US
                                     ? phase_us
                                     : STATUS_LED_SEEK_CYCLE_US - phase_us;
        const unsigned linear_level =
            (ramp_us * STATUS_LED_MAX_LEVEL) / STATUS_LED_SEEK_HALF_CYCLE_US;
        level = (linear_level * linear_level + STATUS_LED_MAX_LEVEL - 1u) /
                STATUS_LED_MAX_LEVEL;
    }

    status_led_set_level(level);
}

/**
 * @brief Adopt the newest complete source frame at a VGA frame boundary.
 *
 * The prior frame remains displayed when capture has not completed a newer
 * frame. A claimed buffer is released only after its replacement is active.
 */
static void select_frame_for_next_vga_frame(void) {
    increment_counter(&vga_statistics.generated_frames);
    p2000t_video_renderer_begin_frame();
    display_state.no_signal_artwork =
        (p2000t_no_signal_artwork_t)load_statistic(
            &requested_no_signal_artwork);
    display_state.signal_present = p2000t_capture_signal_present();
    store_statistic(&vga_statistics.signal_present,
                    display_state.signal_present ? 1u : 0u);
    store_statistic(&vga_statistics.no_signal_artwork,
                    (uint32_t)display_state.no_signal_artwork);

    uint32_t sequence;
    const int next_buffer = p2000t_capture_acquire_latest_frame(&sequence);
    if (next_buffer < 0) {
        if (display_state.buffer_index >= 0) {
            increment_counter(&vga_statistics.repeated_frames);
        }
        if (!display_state.signal_present) {
            increment_counter(&vga_statistics.signal_lost_frames);
        }
        return;
    }

    const int previous_buffer = display_state.buffer_index;
    display_state.buffer_index = next_buffer;
    display_state.frame = p2000t_capture_buffer((unsigned)next_buffer);
    store_statistic(&vga_statistics.displayed_sequence, sequence);
    increment_counter(&vga_statistics.source_frame_swaps);
    if (previous_buffer >= 0) {
        p2000t_capture_release_frame((unsigned)previous_buffer);
    }
}

/**
 * @brief Record scanvideo identifier discontinuities for diagnostics.
 *
 * @param scanline_id Identifier assigned to the current logical scanline.
 */
static void track_scanline_id(uint32_t scanline_id) {
    if (display_state.have_previous_scanline_id) {
        const uint32_t previous_y =
            display_state.previous_scanline_id & 0xffffu;
        const uint32_t expected =
            previous_y + 1u < P2000T_VGA_RENDER_HEIGHT
                ? display_state.previous_scanline_id + 1u
                : (display_state.previous_scanline_id & 0xffff0000u) + 0x10000u;
        if (scanline_id != expected) {
            increment_counter(&vga_statistics.scanline_id_gaps);
        }
    }
    display_state.previous_scanline_id = scanline_id;
    display_state.have_previous_scanline_id = true;
}

/**
 * @brief Render one logical VGA scanline from the selected display state.
 *
 * @param scanline_buffer Scanvideo buffer supplied for generation.
 */
static void render_scanline(scanvideo_scanline_buffer_t *scanline_buffer) {
    const unsigned y = scanvideo_scanline_number(scanline_buffer->scanline_id);
    track_scanline_id(scanline_buffer->scanline_id);

    if (scanline_buffer->data_max < P2000T_RAW_SCANLINE_WORDS) {
        scanline_buffer->data_used = 0;
        scanline_buffer->status = SCANLINE_ERROR;
        return;
    }
    if (y == 0u) {
        select_frame_for_next_vga_frame();
    }
    if (!display_state.signal_present || display_state.buffer_index < 0) {
        p2000t_video_render_no_signal_scanline(scanline_buffer, y,
                                               display_state.no_signal_artwork);
        return;
    }
    p2000t_video_render_source_scanline(scanline_buffer, display_state.frame,
                                        y);
}

/**
 * @brief Produce deadline-critical VGA scanlines continuously on core 1.
 *
 * This function signals core 0 once it is running and then never returns.
 */
static void __not_in_flash_func(vga_core_main)(void) {
    hard_assert(flash_safe_execute_core_init());
    multicore_fifo_push_blocking(VGA_READY_MAGIC);
    while (true) {
        scanvideo_scanline_buffer_t *scanline_buffer =
            scanvideo_begin_scanline_generation(true);
        render_scanline(scanline_buffer);
        scanvideo_end_scanline_generation(scanline_buffer);
    }
}
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
int main(void) {
    configure_system_clock();
    stdio_init_all();
    p2000t_settings_defaults(&current_settings, &current_reconstruction_mode);
    stored_settings_valid =
        p2000t_settings_load(&stored_settings, &stored_reconstruction_mode);
    if (stored_settings_valid) {
        current_settings = stored_settings;
        current_reconstruction_mode = stored_reconstruction_mode;
    }
    /* Builds without a safe window implementation must never revive an older
       experimental six-tap selection from flash. */
    if (!P2000T_CAPTURE_WINDOW_REALTIME_SAFE &&
        current_reconstruction_mode >=
            P2000T_CONTROL_SAMPLE_RECONSTRUCTION_WINDOW_FIRST) {
        current_reconstruction_mode =
            P2000T_CONTROL_DEFAULT_SAMPLE_RECONSTRUCTION;
    }
    p2000t_video_renderer_initialize();
    p2000t_video_renderer_set_source_palette(current_settings.palette);
    select_sample_reconstruction(current_reconstruction_mode, true);

#if defined(PICO_RP2350) && PICO_RP2350
    const bool defer_window_engine =
        current_reconstruction_mode >=
        P2000T_CONTROL_SAMPLE_RECONSTRUCTION_WINDOW_FIRST;
    if (defer_window_engine) {
        /* Bootstrap through the proven two-tap engine. A completed frame then
           performs the normal frame-boundary transition into the requested
           batched window mode after VGA startup is fully established. */
        hard_assert(p2000t_capture_set_reconstruction_mode(
            P2000T_CONTROL_SAMPLE_RECONSTRUCTION_RAW));
    }
#endif

    /* Scanvideo owns PIO0 and its fixed DMA channel. Capture then claims PIO1
       and two otherwise-unused DMA channels. */
    if (!scanvideo_setup(&firmware_vga_mode)) {
        panic("Unable to initialize VGA scanvideo");
    }
    p2000t_capture_start();
    p2000t_capture_set_first_visible_scanline(
        current_settings.first_visible_scanline);
    p2000t_capture_set_sample_phase(current_settings.sample_phase);
    p2000t_capture_set_odd_line_phase(current_settings.odd_line_phase);
    p2000t_capture_set_sample_rate_trim(
        p2000t_settings_sample_rate_trim(&current_settings));
    p2000t_capture_set_horizontal_offset(current_settings.horizontal_offset);
    store_statistic(&requested_no_signal_artwork,
                    p2000t_settings_artwork(&current_settings));
    multicore_launch_core1(vga_core_main);
    if (multicore_fifo_pop_blocking() != VGA_READY_MAGIC) {
        panic("Unable to start VGA rendering core");
    }
    scanvideo_timing_enable(true);
#if defined(PICO_RP2350) && PICO_RP2350
    if (defer_window_engine) {
        hard_assert(p2000t_capture_set_reconstruction_mode(
            current_reconstruction_mode));
    }
#endif
    status_led_initialize();

    bool announced = false;
    while (true) {
#if defined(PICO_RP2350) && PICO_RP2350
        const bool capture_work_pending = p2000t_capture_service();
#endif
        const bool signal_present =
            load_statistic(&vga_statistics.signal_present) != 0u;
        status_led_service(signal_present);
        if (!stdio_usb_connected()) {
            announced = false;
#if defined(PICO_RP2350) && PICO_RP2350
            sleep_us(capture_work_pending ? 100u
                                          : STATUS_LED_SERVICE_INTERVAL_US);
#else
            sleep_us(STATUS_LED_SERVICE_INTERVAL_US);
#endif
            continue;
        }
        if (!announced) {
            sleep_ms(100);
            announce_usb_connection();
            announced = true;
        }
        poll_usb_commands();
#if defined(PICO_RP2350) && PICO_RP2350
        if (p2000t_diagnostics_active()) {
            p2000t_diagnostics_service();
            sleep_us(100u);
            continue;
        }
        if (p2000t_usb_stream_active()) {
            p2000t_usb_stream_service(
                signal_present,
                load_statistic(&vga_statistics.no_signal_artwork));
            sleep_us(100u);
            continue;
        }
#endif
        sleep_us(STATUS_LED_SERVICE_INTERVAL_US);
    }
}

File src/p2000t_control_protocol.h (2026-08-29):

/*
 * SPDX-FileCopyrightText: 2026 Ivo Filot <ivo@ivofilot.nl>
 * SPDX-License-Identifier: GPL-3.0-or-later
 */

#ifndef P2000T_CONTROL_PROTOCOL_H
#define P2000T_CONTROL_PROTOCOL_H

/** Structured host-to-Pico control packet layout. */
enum {
    P2000T_CONTROL_MAGIC_0 = 0xa5,
    P2000T_CONTROL_MAGIC_1 = 0x5a,
    P2000T_CONTROL_VERSION = 1,
    P2000T_CONTROL_PACKET_SIZE = 12,
    P2000T_CONTROL_CRC_OFFSET = 10,

    P2000T_CONTROL_GET_SETTINGS = 1,
    P2000T_CONTROL_SET_VERTICAL = 2,
    P2000T_CONTROL_SET_PHASE = 3,
    P2000T_CONTROL_SET_HORIZONTAL = 4,
    P2000T_CONTROL_SET_ARTWORK = 5,
    P2000T_CONTROL_SET_PALETTE = 6,
    P2000T_CONTROL_SAVE_SETTINGS = 7,
    P2000T_CONTROL_LOAD_SETTINGS = 8,
    P2000T_CONTROL_FACTORY_DEFAULTS = 9,
    P2000T_CONTROL_SET_ODD_LINE_PHASE = 10,
    P2000T_CONTROL_SET_SAMPLE_RATE_TRIM = 11,
    P2000T_CONTROL_SET_SAMPLE_RECONSTRUCTION = 12,
    P2000T_CONTROL_START_DIAGNOSTICS = 13,
    P2000T_CONTROL_CANCEL_DIAGNOSTICS = 14,
    P2000T_CONTROL_ACK_DIAGNOSTIC_RECORD = 15,
    P2000T_CONTROL_RETRY_DIAGNOSTIC_RECORD = 16,

    P2000T_CONTROL_PALETTE_COLORS = 8,
    P2000T_CONTROL_RGB444_MAX = 0x0fff,

    P2000T_CONTROL_MIN_VERTICAL = 1,
    P2000T_CONTROL_MAX_VERTICAL = 73,
    P2000T_CONTROL_DEFAULT_VERTICAL = 57,
    P2000T_CONTROL_MIN_PHASE = -10,
    P2000T_CONTROL_MAX_PHASE = 10,
    P2000T_CONTROL_DEFAULT_PHASE = 0,
    P2000T_CONTROL_MIN_ODD_LINE_PHASE = -10,
    P2000T_CONTROL_MAX_ODD_LINE_PHASE = 10,
    P2000T_CONTROL_DEFAULT_ODD_LINE_PHASE = 0,
    P2000T_CONTROL_MIN_SAMPLE_RATE_TRIM = -8,
    P2000T_CONTROL_MAX_SAMPLE_RATE_TRIM = 8,
    P2000T_CONTROL_DEFAULT_SAMPLE_RATE_TRIM = 0,
    P2000T_CONTROL_SAMPLE_RECONSTRUCTION_RAW = 0,
    P2000T_CONTROL_SAMPLE_RECONSTRUCTION_SECOND_TAP = 1,
    P2000T_CONTROL_SAMPLE_RECONSTRUCTION_SHARP_GUARDED = 2,
    P2000T_CONTROL_SAMPLE_RECONSTRUCTION_WINDOW_CENTER = 3,
    P2000T_CONTROL_SAMPLE_RECONSTRUCTION_WINDOW_CHANNEL_MAJORITY = 4,
    P2000T_CONTROL_SAMPLE_RECONSTRUCTION_WINDOW_COLOR_EARLY = 5,
    P2000T_CONTROL_SAMPLE_RECONSTRUCTION_WINDOW_COLOR_LATE = 6,
    P2000T_CONTROL_SAMPLE_RECONSTRUCTION_WINDOW_CONFIDENCE_GUARD = 7,
    P2000T_CONTROL_SAMPLE_RECONSTRUCTION_COUNT = 8,
    P2000T_CONTROL_SAMPLE_RECONSTRUCTION_WINDOW_FIRST =
        P2000T_CONTROL_SAMPLE_RECONSTRUCTION_WINDOW_CENTER,
    P2000T_CONTROL_DEFAULT_SAMPLE_RECONSTRUCTION =
        P2000T_CONTROL_SAMPLE_RECONSTRUCTION_RAW,
    P2000T_CONTROL_PICO2_DEFAULT_PHASE = 0,
    P2000T_CONTROL_PICO2_DEFAULT_ODD_LINE_PHASE = 1,
    P2000T_CONTROL_PICO2_DEFAULT_SAMPLE_RECONSTRUCTION =
        P2000T_CONTROL_SAMPLE_RECONSTRUCTION_WINDOW_COLOR_LATE,
    P2000T_CONTROL_MIN_HORIZONTAL = 0,
    P2000T_CONTROL_MAX_HORIZONTAL = 60,
    P2000T_CONTROL_HORIZONTAL_STEP = 6,
    P2000T_CONTROL_DEFAULT_HORIZONTAL = 48,
    P2000T_CONTROL_DEFAULT_ARTWORK = 2,

    P2000T_CONFIGURATION_STATE_LEGACY_SIZE = 32,
    P2000T_CONFIGURATION_STATE_SIZE = 64,
    P2000T_CONFIGURATION_STATE_VERSION = 5,
    P2000T_CONFIGURATION_STATE_RUNTIME_RECONSTRUCTION_VERSION = 5,
    P2000T_CONFIGURATION_STATE_RECONSTRUCTION_VERSION = 4,
    P2000T_CONFIGURATION_STATE_RATE_TRIM_VERSION = 3,
    P2000T_CONFIGURATION_STATE_ODD_LINE_PHASE_VERSION = 2,
    P2000T_CONFIGURATION_STATE_LEGACY_VERSION = 1,
    P2000T_CONFIGURATION_FLAG_STORED_AVAILABLE = 1u << 0,
    P2000T_CONFIGURATION_FLAG_MATCHES_STORED = 1u << 1,
    P2000T_CONFIGURATION_FLAG_SAVE_FAILED = 1u << 2,
    P2000T_CONFIGURATION_CAPTURE_OPTIONS_OFFSET = 14,
    P2000T_CONFIGURATION_ODD_LINE_PHASE_OFFSET = 15,
    P2000T_CONFIGURATION_PALETTE_OFFSET = 16,
    P2000T_CONFIGURATION_ARTWORK_MASK = 0x03,
    P2000T_CONFIGURATION_SAMPLE_RECONSTRUCTION_SHIFT = 2,
    P2000T_CONFIGURATION_SAMPLE_RECONSTRUCTION_MASK = 0x04,
    P2000T_CONFIGURATION_RATE_TRIM_SHIFT = 3,
    P2000T_CONFIGURATION_RATE_TRIM_VALUE_MASK = 0x1f,

    P2000T_CONFIGURATION_RUNTIME_RECONSTRUCTION_OFFSET = 32,
    P2000T_CONFIGURATION_CAPTURE_ENGINE_OFFSET = 33,
    P2000T_CONFIGURATION_WINDOW_SAMPLES_OFFSET = 34,
    P2000T_CONFIGURATION_CAPTURE_FLAGS_OFFSET = 35,
    P2000T_CONFIGURATION_WINDOW_FRAMES_OFFSET = 36,
    P2000T_CONFIGURATION_LAST_CORRECTED_OFFSET = 40,
    P2000T_CONFIGURATION_LAST_AMBIGUOUS_OFFSET = 44,
    P2000T_CONFIGURATION_LAST_RED_CORRECTED_OFFSET = 48,
    P2000T_CONFIGURATION_LAST_GREEN_CORRECTED_OFFSET = 52,
    P2000T_CONFIGURATION_LAST_BLUE_CORRECTED_OFFSET = 56,
    P2000T_CONFIGURATION_LINE_DEADLINE_MISSES_OFFSET = 60,

    P2000T_CAPTURE_ENGINE_TWO_TAP = 0,
    P2000T_CAPTURE_ENGINE_WINDOWED = 1,
    P2000T_CONFIGURATION_CAPTURE_FLAG_WINDOW_SUPPORTED = 1u << 0,
    P2000T_CONFIGURATION_CAPTURE_FLAG_ENGINE_SWITCH_PENDING = 1u << 1,
};

#define P2000T_CONFIGURATION_STATE_MAGIC "P2CS"

#endif

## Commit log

2026-08-24 Interim commit firmware
    [p2000t-video-to-vga-adapter.kicad_pcb, p2000t-video-to-vga-adapter.kicad_sch]
2026-08-26 Polishing code, creating enclosure
    [bottom.stl, p2000t-vga-v1.step, p2000t-video-to-vga-adapter.kicad_pcb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]
2026-08-27 Initial commit background images
    [bottom.stl, top.stl]
2026-08-27 Polishing enclosure and updating version
    [top.stl]
2026-08-27 Changing deployment
    [bottom.stl, configuration_dialog.h, top.stl]
2026-08-27 Implementing LED indicator
    [configuration_dialog.h]
2026-08-28 Fixing LICENSE details, polishing README.md, updating version
    [p2000t-video-to-vga-adapter.kicad_pcb]
2026-08-28 Initial commit sampling mode
    [configuration_dialog.h]
2026-08-28 Fixing flash save bug
    [firmware.c, p2000t_capture.c, p2000t_capture.h]

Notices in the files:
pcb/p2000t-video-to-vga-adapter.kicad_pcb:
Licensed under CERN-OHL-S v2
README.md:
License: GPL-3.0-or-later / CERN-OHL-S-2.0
